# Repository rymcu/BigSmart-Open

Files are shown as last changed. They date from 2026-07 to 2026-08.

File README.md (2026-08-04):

# RYMCU BigSmart AI助手

**中文** | [English](README.en.md)

基于 **ESP32-S3-WROOM-1-N16R8** 的智能语音交互开发板，集成音频系统、显示系统、摄像头、传感器、MicroSD 存储和电池供电等多种外设。

## 主要特性

- **主控**: ESP32-S3-WROOM-1-N16R8 (16 MB Flash + 8 MB PSRAM)
- **音频**: ES8311 DAC + ES7210 四通道 ADC + NS4150B 功放
- **显示**: 2.8" ST7789 LCD (320 x 240) + GT911 电容触摸屏
- **摄像头**: GC0308 (640 x 480 @ 16 FPS)
- **传感器**: QMI8658 六轴加速度计/陀螺仪
- **存储**: MicroSD 卡槽
- **电池**: 2500mAh 3.7V 锂离子电池
- **其他**: WS2812B RGB LED、电池充电管理、按键输入

## 实物展示

| Home | Xiaozhi |
|---|---|
| BigSmart Home | BigSmart Xiaozhi |

| Page 1 | Tetris |
|---|---|
| BigSmart Page 1 | BigSmart Tetris |

## 第三方支持

RYMCU BigSmart 已合并到以下官方开源项目，方便用户基于主线生态进行固件开发和应用验证。

| 小智 AI 官方 | 乐鑫科技 Espressif 官方 |
|---|---|
| [78/xiaozhi-esp32](https://github.com/78/xiaozhi-esp32)<br>[PR #1958](https://github.com/78/xiaozhi-esp32/pull/1958) | [espressif/esp-brookesia](https://github.com/espressif/esp-brookesia)<br>[PR #94](https://github.com/espressif/esp-brookesia/pull/94) |
| RYMCU BigSmart in xiaozhi-esp32 | RYMCU BigSmart in esp-brookesia |

## 开源硬件 PCB 工程

`BigSmart` 硬件由主板和麦克风按键副板组成。硬件文件夹下提供了完整开源工程文件，只需将对应工程导入立创 `EDA` 专业版即可使用。

| 主板 | 麦克风按键副板 |
|---|---|
| BigSmart 主板 PCB | BigSmart 麦克风按键副板 PCB |

## 开源外壳工程

外壳开源，直接3D打印即可。

| 外壳上盖 | 外壳底壳 |
|---|---|
| BigSmart 外壳上盖 | BigSmart 外壳底壳 |

`enclosure/` 同时提供主板与麦克风按键副板的 STEP 结构模型：

- `3D_BigSmart_2026-01-15.step`：主板结构模型，也是网站 3D 主板模型的生成源。
- `3D_bs-mic_2026-02-01.step`：麦克风按键副板结构模型。

修改主板 STEP 后，可在 `site/` 目录运行 `pnpm model:build`，重新生成 `site/public/models/bigsmart-mainboard.glb` 及其元数据。

## 目录结构

```text
BigSmart-Open/
├── hardware/
│   ├── mainboard/          # 主板 EDA 工程及原理图
│   └── mics-keys/          # 麦克风按键板 EDA 工程及原理图
├── enclosure/              # 外壳 3D 设计文件 (Fusion 360)
├── docs/
│   ├── zh/                 # 中文文档
│   └── en/                 # English documentation
├── firmware/               # 预编译合并固件
├── images/                 # 文档引用图片
├── tools/
│   └── video-converter/    # BigSmart 视频转换器
└── README.md
```

## 文档

| 中文 | English |
|---|---|
| [快速使用指南](docs/zh/quick-start.md) | [Quick Start Guide](docs/en/quick-start.md) |
| [产品介绍书](docs/zh/product-brief.md) | [Product Brief](docs/en/product-brief.md) |
| [用户详细使用手册](docs/zh/user-manual.md) | [User Manual](docs/en/user-manual.md) |
| [硬件配置说明](docs/zh/hardware.md) | [Hardware Configuration](docs/en/hardware.md) |
| [视频转换器使用说明](docs/zh/video-converter.md) | [Video Converter User Guide](docs/en/video-converter.md) |

## 固件

- [RYMCU 官方固件](firmware/rymcu-V2.3.28-merged.bin)
- [小智 AI 官方固件](firmware/xiaozhi-esp32-merged.bin)
- [乐鑫科技官方固件](firmware/espressif-brookesia-merged.bin)
- [固件烧录说明](firmware/README.md)

当前推荐使用 `rymcu-V2.3.28-merged.bin`。仓库仍保留 `rymcu-V2.3.19-merged.bin` 作为旧版回退固件。

## 功能展示

点击屏幕的`Music app`和`Video app`即可播放`SD`卡`mp3`音乐和视频。

| 音乐播放 | 视频播放 |
|---|---|
| 音乐播放界面 | 视频播放界面 |

## 许可证

- **个人 DIY / 非商业用途**：遵循 [Apache-2.0](LICENSE) 开源许可证。
- **商业用途**：需取得 RYMCU 商用授权，请联系 [RYMCU 官方](mailto:hugh@rymcu.com) 获取授权详情。

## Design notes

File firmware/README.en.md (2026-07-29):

# RYMCU BigSmart Firmware Flashing Guide

[中文](README.md) | **English**

This directory contains prebuilt merged firmware images that can be flashed directly to the RYMCU BigSmart AI assistant. The images are organized by source: RYMCU official, Xiaozhi AI official, and Espressif official.

## Firmware Images

| File | Source | Description |
|---|---|---|
| `rymcu-V2.3.28-merged.bin` | RYMCU official | Recommended merged firmware image packaged by RYMCU for BigSmart |
| `rymcu-V2.3.19-merged.bin` | RYMCU official | Legacy fallback merged firmware image |
| `xiaozhi-esp32-merged.bin` | Xiaozhi AI official | Merged firmware image for the [78/xiaozhi-esp32](https://github.com/78/xiaozhi-esp32) upstream ecosystem |
| `espressif-brookesia-merged.bin` | Espressif official | Merged firmware image for the [espressif/esp-brookesia](https://github.com/espressif/esp-brookesia) upstream ecosystem |

`rymcu-V2.3.28-merged.bin` is synced from the prebuilt V2.3.28 merged image under `E:\RYMCU\xiaozhi`. It includes Weather, Calendar, Codex Status, Smart Home MQTT/Endpoint overview support, the NES launcher, and NES dedicated boot mode. This prebuilt image does not include the later NES display, audio, and volume-control changes from the 2026-07-28 commit `b1d1c08`.

## Before Flashing

Prepare the following items:

- RYMCU BigSmart AI assistant.
- USB Type-C cable that supports data transfer.
- A Windows computer and any flashing tool that supports ESP32-S3.

Put the device into download mode before flashing:

1. Hold the BigSmart Boot button.
2. Hold the power button to turn on the device.
3. Release all buttons after the device enters download mode.
4. Check the serial port in Device Manager, such as `COM8`.

All flashing methods below require the device to be in download mode first. After flashing, power on the device again to run the new firmware.

## Offline Flashing

Choose any one of the following offline tools. All merged firmware images must be written to Flash offset `0x0`.

### Espressif Flash Download Tool

Flash Download Tool is Espressif's official offline flashing utility. It is suitable for manually selecting the firmware image and writing it through a graphical interface.

Download link: [Flash Download Tool](https://docs.espressif.com/projects/esp-test-tools/en/latest/esp32/production_stage/tools/flash_download_tool.html)

After downloading and extracting the package, run the `.exe` file, then select the chip, serial port, flash address, and firmware image as shown in the tool.

Flash Download Tool start screen

Flash Download Tool flashing configuration

### RYMCU Serial Debug Assistant

RYMCU Serial Debug Assistant provides a graphical serial flashing workflow for quickly selecting and writing a merged firmware image to BigSmart.

Download link: [RYCOM 2.6.3](https://github.com/rymcu/RYCOM/releases/tag/2.6.3)

After installation, open the tool, select the BigSmart serial port, choose the firmware image, and start flashing as shown below.

RYMCU Serial Debug Assistant flashing screen

### RYMCU RODAK Tool

RODAK is a firmware download tool provided by RYMCU. It can also flash BigSmart merged firmware images.

Download link: [RODAK Releases](https://github.com/rymcu/rodak-releases)

After installation, open the tool, select the BigSmart serial port, choose the firmware image, and start flashing as shown below.

RODAK flashing screen

## Online Flashing

### Espressif ESP Launchpad

ESP Launchpad is Espressif's official web flashing tool. It can connect to the serial port and write firmware directly from the browser.

Online flashing link: [ESP Launchpad](https://espressif.github.io/esp-launchpad/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)

Steps:

1. Open the page and click `Connect`.
2. Select the BigSmart serial port in the browser's port list and connect.
3. Click `DIY`.
4. Set the flash address to `0x0`.
5. Select the merged firmware image to flash.
6. Click `Program` to start flashing.

ESP Launchpad flashing screen

## Check After Flashing

After flashing, the device restarts automatically. In a normal startup:

- The screen turns on and enters the Launcher.
- The home screen shows `rymcu-bigsmart` and the firmware version.
- Serial logs print `RYMCU BigSmart - Starting...`.
- If an SD card is inserted, logs show `SD card mounted at /sdcard`.

## Troubleshooting

| Problem | Solution |
|---|---|
| Serial port not found | Use a data-capable USB cable and check drivers/device manager |
| Flashing fails | Re-enter download mode, close any serial terminal using the port, and retry |
| No display after flashing | Confirm the image was written at `0x0`, power-cycle the board, and check power |
| Wi-Fi cannot connect | Use 2.4G Wi-Fi and reconfigure the network in Settings |

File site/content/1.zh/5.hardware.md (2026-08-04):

---
title: 硬件配置说明
description: BigSmart 硬件组件、接口、电源、外设和 GPIO 分配说明。
navigation:
  title: 硬件配置说明
  icon: i-lucide-cpu
links:
  - label: English
    icon: i-lucide-languages
    to: /en/docs/hardware
---
## 概述

RYMCU BigSmart 是一款基于 ESP32-S3 的智能语音交互助手，集成了音频系统、显示系统、摄像头、传感器等多种外设。本文档详细列出了开发板使用的硬件组件及其 GPIO 引脚分配。

## 主控芯片

| 项目 | 规格 |
|---|---|
| 主控 | ESP32-S3-WROOM-1-N16R8 |
| 目标配置 | esp32s3 |
| PSRAM | 支持 |

---

## 1. 音频系统

### 1.1 音频编解码芯片

| 芯片 | 型号 | 功能 | I2C地址 |
|---|---|---|---|
| DAC | ES8311 | 音频输出 | 0x18 |
| ADC | ES7210 | 四通道音频输入 | 0x82（对应硬件7位地址0x41） |

### 1.2 I2S 音频接口

| 功能 | GPIO | 说明 |
|---|---|---|
| MCLK | GPIO38 | 主时钟 |
| WS (LRCK) | GPIO13 | 字选择/左右声道时钟 |
| BCLK | GPIO14 | 位时钟 |
| DIN | GPIO12 | I2S数据输入 (ADC -> ESP32) |
| DOUT | GPIO45 | I2S数据输出 (ESP32 -> DAC) |

### 1.3 麦克风通道映射

ES7210 四通道 ：

MIC1：主麦克风

MIC2：副麦克风

MIC3：AEC参考(连接到音频解码ES8311的输出)

MIC4：悬空

### 1.4 功放

采用NS4150B，使能引脚对应IO0（PCA9557），默认低电平。

### 2 I2C 控制接口

音频编解码器(ES8311/ES7210)、触摸屏(GT911)、IO扩展器(PCA9557)、六轴传感器(QMI8658)共用同一I2C总线.

| 功能 | GPIO | 说明 |
|---|---|---|
| SDA | GPIO1 | I2C数据线 |
| SCL | GPIO2 | I2C时钟线 |

### 3 IO 扩展器 (PCA9557)

| 项目 | 值 |
|---|---|
| 芯片型号 | PCA9557 |
| I2C地址 | 0x19 |
| 功能 | 控制音频编解码器使能引脚 |

IO功能分配：

| IO（PCA9557） | 信号 | 功能 |
| --- | --- | --- |
| IO0 | LCD_CS | 屏幕片选（默认上拉） |
| IO1 | PA_EN | 功放使能（默认下拉） |
| IO2 | DVP_PWDN | 摄像头电源_down（默认上拉） |
| IO3 | NFC_RST  | NFC复位（预留） |
| IO4-IO7 | / | 悬空 |

---

## 4. 显示系统

### 4.1 LCD 显示屏

| 项目 | 规格 |
|---|---|
| 驱动IC | ST7789 |
| 分辨率 | 320 x 240 |
| 接口 | SPI |
| 颜色深度 | 16-bit (RGB565) |
| SPI时钟 | 80 MHz |

### 4.2 SPI 显示接口

| 功能 | GPIO | 说明 |
|---|---|---|
| MOSI | GPIO40 | SPI主输出从输入 |
| SCLK | GPIO41 | SPI时钟 |
| DC | GPIO39 | 数据/命令选择 |
| RESET | / | 上电复位 |
| CS | / | IO0（PCA9557） |

### 4.3 背光控制

| 功能 | GPIO | 说明 |
|---|---|---|
| 背光控制 | GPIO42 | PWM调光 (输出反相) |

### 4.4 触摸屏

| 项目 | 规格 |
|---|---|
| 驱动IC | GT911 |
| 接口 | I2C |
| I2C地址 | 0x5D (默认) / 0x14 (备用) |
| I2C总线 | 与音频共用同一I2C总线 |
| 复位 | 上电复位 |

---

## 5. 摄像头系统

### 5.1 摄像头模块

| 项目 | 规格 |
|---|---|
| 传感器 | GC0308 |
| 接口 | DVP (Digital Video Port) |
| 输出格式 | YUV422 |
| 分辨率 | 640 x 480 |
| 帧率 | 16 FPS |
| XCLK频率 | 16 MHz |

### 5.2 DVP 接口引脚

| 功能 | GPIO | 说明 |
|---|---|---|
| XCLK | GPIO5 | 外部时钟输出 |
| PCLK | GPIO7 | 像素时钟输入 |
| VSYNC | GPIO44 | 垂直同步 |
| HREF | GPIO46 | 水平参考 |
| D0 | GPIO16 | 数据位0 |
| D1 | GPIO18 | 数据位1 |
| D2 | GPIO8 | 数据位2 |
| D3 | GPIO17 | 数据位3 |
| D4 | GPIO15 | 数据位4 |
| D5 | GPIO6 | 数据位5 |
| D6 | GPIO4 | 数据位6 |
| D7 | GPIO9 | 数据位7 |
| SIOD (SDA) | GPIO1 | I2C数据 (共用) |
| SIOC (SCL) | GPIO2 | I2C时钟 (共用) |
| PWDN | / | IO2（PCA9557） |
| RESET | / | 上电复位 |

---

## 6. SD卡接口

### SD 引脚

| 功能 | GPIO | 说明 |
|---|---|---|
| CLK | GPIO47 | 时钟线 |
| CMD | GPIO48 | 命令线 |
| DAT0 | GPIO21 | 数据线0 |
| DAT1 | / | 悬空 |
| DAT2 | / | 悬空 |
| CD/DAT3 | / | 上拉 |

---

## 7. 传感器系统

### 7.1 六轴传感器 (QMI8658)

| 项目 | 规格 |
|---|---|
| 芯片型号 | QMI8658 |
| 功能 | 3轴加速度计 + 3轴陀螺仪 |
| I2C地址 | 0x6A |
| I2C总线 | 与音频共用同一I2C总线 |
| 采样间隔 | 100ms (可配置) |
| 功能 | 姿态检测、晃动检测 |

---

## 8. 按键与LED

### 8.1 按键配置

| 功能 | GPIO | 说明 |
|---|---|---|
| 电源按键 | / | 长按3s开关机  |
| Boot按键 | GPIO0 | 开机/功能按键 |
| 自定义按键 | GPIO10 | 自定义 |
| RGB LED | GPIO43 (UART0_TX复用) | 1颗WS2812B |

---

## 9. 电池监测

| 功能 | GPIO | 说明 |
|---|---|---|
| 充电状态检测 | GPIO3 | 低电平表示正在充电 |
| 电池电压检测 | GPIO11 | 2个10K电阻分压 |

---

## 10. 引脚汇总表

### 10.1 按GPIO编号排序

| GPIO | 功能 | 方向 | 说明 |
|---|---|---|---|
| GPIO0 | Boot按键 | 输入 | 低电平有效 |
| GPIO1 | I2C SDA | 双向 | 音频/触摸/传感器共用 |
| GPIO2 | I2C SCL | 输出 | 音频/触摸/传感器共用 |
| GPIO3 | 充电状态 | 输入 | 低电平表示正在充电 |
| GPIO4 | Camera D6 | 输入 | DVP数据 |
| GPIO5 | Camera XCLK | 输出 | 摄像头时钟 |
| GPIO6 | Camera D5 | 输入 | DVP数据 |
| GPIO7 | Camera PCLK | 输入 | 像素时钟 |
| GPIO8 | Camera D2 | 输入 | DVP数据 |
| GPIO9 | Camera D7 | 输入 | DVP数据 |
| GPIO10 | 按键 | 输入 | 自定义 |
| GPIO11 | 电池电压 | 输入 | 2个10K电阻分压 |
| GPIO12 | I2S DIN | 输入 | ADC数据输入 |
| GPIO13 | I2S WS | 双向 | 字选择 |
| GPIO14 | I2S BCLK | 输出 | 位时钟 |
| GPIO15 | Camera D4 | 输入 | DVP数据 |
| GPIO16 | Camera D0 | 输入 | DVP数据 |
| GPIO17 | Camera D3 | 输入 | DVP数据 |
| GPIO18 | Camera D1 | 输入 | DVP数据 |
| GPIO21 | SD DAT0 | 双向 | SD卡数据 |
| GPIO38 | I2S MCLK | 输出 | 主时钟 |
| GPIO39 | LCD DC | 输出 | 数据/命令选择 |
| GPIO40 | SPI MOSI | 输出 | SPI数据 |
| GPIO41 | SPI SCLK | 输出 | SPI时钟 |
| GPIO42 | 背光控制 | 输出 | PWM (反相) |
| GPIO43 | RGB LED | 输出 | WS2812B数据 |
| GPIO44 | Camera VSYNC | 输入 | 垂直同步 |
| GPIO45 | I2S DOUT | 输出 | DAC数据输出 |
| GPIO46 | Camera HREF | 输入 | 水平参考 |
| GPIO47 | SD CLK | 输出 | SD卡时钟 |
| GPIO48 | SD CMD | 双向 | SD卡命令 |

### 10.2 按功能模块分类

| 模块 | GPIO列表 |
|---|---|
| I2C总线 | GPIO1 (SDA), GPIO2 (SCL) |
| I2S音频 | GPIO38 (MCLK), GPIO13 (WS), GPIO14 (BCLK), GPIO12 (DIN), GPIO45 (DOUT) |
| SPI显示 | GPIO40 (MOSI), GPIO41 (SCLK), GPIO39 (DC) |
| DVP摄像头 | GPIO5, GPIO7, GPIO44, GPIO46, GPIO16, GPIO18, GPIO8, GPIO17, GPIO15, GPIO6, GPIO4, GPIO9 |
| SD卡 | GPIO47 (CLK), GPIO48 (CMD), GPIO21 (DAT0) |
| 背光 | GPIO42 |
| RGB LED | GPIO43 |
| 按键 | GPIO0 (Boot), GPIO10 (自定义) |
| 检测 | GPIO3 (充电状态), GPIO11 (电池电压) |

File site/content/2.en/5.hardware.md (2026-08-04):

---
title: Hardware Configuration
description: Hardware components, interfaces, power, peripherals, and GPIO assignments.
navigation:
  title: Hardware Configuration
  icon: i-lucide-cpu
links:
  - label: 中文
    icon: i-lucide-languages
    to: /docs/hardware
---
## Overview

RYMCU BigSmart is an ESP32-S3 smart voice interaction development board with integrated audio, display, camera, sensor, storage, power, and button peripherals. This document summarizes the main hardware components and GPIO assignments.

## Main Controller

| Item | Specification |
|---|---|
| MCU | ESP32-S3-WROOM-1-N16R8 |
| Target | `esp32s3` |
| PSRAM | Supported |

## 1. Audio System

### 1.1 Audio Codec Chips

| Chip | Model | Function | I2C address |
|---|---|---|---|
| DAC | ES8311 | Audio output | `0x18` |
| ADC | ES7210 | Four-channel audio input | `0x82` eight-bit address, `0x41` seven-bit hardware address |

### 1.2 I2S Audio Interface

| Function | GPIO | Description |
|---|---|---|
| MCLK | GPIO38 | Master clock |
| WS / LRCK | GPIO13 | Word select / left-right clock |
| BCLK | GPIO14 | Bit clock |
| DIN | GPIO12 | I2S data input, ADC to ESP32 |
| DOUT | GPIO45 | I2S data output, ESP32 to DAC |

### 1.3 Microphone Channel Mapping

| ES7210 channel | Function |
|---|---|
| MIC1 | Main microphone |
| MIC2 | Secondary microphone |
| MIC3 | AEC reference, connected to ES8311 output |
| MIC4 | Reserved / floating |

### 1.4 Power Amplifier

The board uses an NS4150B power amplifier. Its enable signal is controlled by IO1 of the PCA9557 and defaults low.

## 2. I2C Control Interface

The ES8311, ES7210, GT911 touch controller, PCA9557 IO expander, and QMI8658 IMU share the same I2C bus.

| Function | GPIO | Description |
|---|---|---|
| SDA | GPIO1 | I2C data |
| SCL | GPIO2 | I2C clock |

## 3. IO Expander

| Item | Value |
|---|---|
| Model | PCA9557 |
| I2C address | `0x19` |
| Function | Controls peripheral enable and selection signals |

| PCA9557 IO | Signal | Function |
|---|---|---|
| IO0 | LCD_CS | LCD chip select, default pull-up |
| IO1 | PA_EN | Amplifier enable, default pull-down |
| IO2 | DVP_PWDN | Camera power down, default pull-up |
| IO3 | NFC_RST | NFC reset, reserved |
| IO4-IO7 | / | Floating |

## 4. Display System

### 4.1 LCD

| Item | Specification |
|---|---|
| Driver IC | ST7789 |
| Resolution | 320 x 240 |
| Interface | SPI |
| Color depth | 16-bit RGB565 |
| SPI clock | 80 MHz |

### 4.2 SPI Display Interface

| Function | GPIO | Description |
|---|---|---|
| MOSI | GPIO40 | SPI data |
| SCLK | GPIO41 | SPI clock |
| DC | GPIO39 | Data/command select |
| RESET | / | Power-on reset |
| CS | / | IO0 of PCA9557 |

### 4.3 Backlight

| Function | GPIO | Description |
|---|---|---|
| Backlight control | GPIO42 | PWM dimming, inverted output |

### 4.4 Touch Panel

| Item | Specification |
|---|---|
| Driver IC | GT911 |
| Interface | I2C |
| I2C address | `0x5D` by default, `0x14` alternative |
| I2C bus | Shared with audio and sensors |
| Reset | Power-on reset |

## 5. Camera System

### 5.1 Camera Module

| Item | Specification |
|---|---|
| Sensor | GC0308 |
| Interface | DVP |
| Output format | YUV422 |
| Resolution | 640 x 480 |
| Frame rate | 16 FPS |
| XCLK frequency | 16 MHz |

### 5.2 DVP Pins

| Function | GPIO | Description |
|---|---|---|
| XCLK | GPIO5 | External clock output |
| PCLK | GPIO7 | Pixel clock input |
| VSYNC | GPIO44 | Vertical sync |
| HREF | GPIO46 | Horizontal reference |
| D0 | GPIO16 | Data bit 0 |
| D1 | GPIO18 | Data bit 1 |
| D2 | GPIO8 | Data bit 2 |
| D3 | GPIO17 | Data bit 3 |
| D4 | GPIO15 | Data bit 4 |
| D5 | GPIO6 | Data bit 5 |
| D6 | GPIO4 | Data bit 6 |
| D7 | GPIO9 | Data bit 7 |
| SIOD / SDA | GPIO1 | Shared I2C data |
| SIOC / SCL | GPIO2 | Shared I2C clock |
| PWDN | / | IO2 of PCA9557 |
| RESET | / | Power-on reset |

## 6. SD Card Interface

| Function | GPIO | Description |
|---|---|---|
| CLK | GPIO47 | Clock |
| CMD | GPIO48 | Command |
| DAT0 | GPIO21 | Data line 0 |
| DAT1 | / | Floating |
| DAT2 | / | Floating |
| CD/DAT3 | / | Pull-up |

## 7. Sensor System

| Item | Specification |
|---|---|
| Model | QMI8658 |
| Function | 3-axis accelerometer + 3-axis gyroscope |
| I2C address | `0x6A` |
| I2C bus | Shared with audio and touch |
| Sampling interval | 100 ms, configurable |
| Typical use | Attitude detection, shake detection |

## 8. Buttons and LED

| Function | GPIO | Description |
|---|---|---|
| Power button | / | Hold for about 3 seconds to power on/off |
| Boot button | GPIO0 | Boot/function button |
| Custom button | GPIO10 | Custom input |
| RGB LED | GPIO43 | One WS2812B LED, reused with UART0_TX |

## 9. Battery Monitoring

| Function | GPIO | Description |
|---|---|---|
| Charging-state detection | GPIO3 | Low level means charging |
| Battery-voltage detection | GPIO11 | Divided by two 10K resistors |

## 10. GPIO Summary

### 10.1 Sorted by GPIO Number

| GPIO | Function | Direction | Description |
|---|---|---|---|
| GPIO0 | Boot button | Input | Active low |
| GPIO1 | I2C SDA | Bidirectional | Shared by audio, touch, and sensors |
| GPIO2 | I2C SCL | Output | Shared by audio, touch, and sensors |
| GPIO3 | Charging state | Input | Low level means charging |
| GPIO4 | Camera D6 | Input | DVP data |
| GPIO5 | Camera XCLK | Output | Camera clock |
| GPIO6 | Camera D5 | Input | DVP data |
| GPIO7 | Camera PCLK | Input | Pixel clock |
| GPIO8 | Camera D2 | Input | DVP data |
| GPIO9 | Camera D7 | Input | DVP data |
| GPIO10 | Button | Input | Custom |
| GPIO11 | Battery voltage | Input | Divided by two 10K resistors |
| GPIO12 | I2S DIN | Input | ADC data input |
| GPIO13 | I2S WS | Bidirectional | Word select |
| GPIO14 | I2S BCLK | Output | Bit clock |
| GPIO15 | Camera D4 | Input | DVP data |
| GPIO16 | Camera D0 | Input | DVP data |
| GPIO17 | Camera D3 | Input | DVP data |
| GPIO18 | Camera D1 | Input | DVP data |
| GPIO21 | SD DAT0 | Bidirectional | SD card data |
| GPIO38 | I2S MCLK | Output | Master clock |
| GPIO39 | LCD DC | Output | Data/command select |
| GPIO40 | SPI MOSI | Output | SPI data |
| GPIO41 | SPI SCLK | Output | SPI clock |
| GPIO42 | Backlight | Output | PWM, inverted |
| GPIO43 | RGB LED | Output | WS2812B data |
| GPIO44 | Camera VSYNC | Input | Vertical sync |
| GPIO45 | I2S DOUT | Output | DAC data output |
| GPIO46 | Camera HREF | Input | Horizontal reference |
| GPIO47 | SD CLK | Output | SD card clock |
| GPIO48 | SD CMD | Bidirectional | SD card command |

### 10.2 Grouped by Function

| Module | GPIO list |
|---|---|
| I2C bus | GPIO1 (SDA), GPIO2 (SCL) |
| I2S audio | GPIO38 (MCLK), GPIO13 (WS), GPIO14 (BCLK), GPIO12 (DIN), GPIO45 (DOUT) |
| SPI display | GPIO40 (MOSI), GPIO41 (SCLK), GPIO39 (DC) |
| DVP camera | GPIO5, GPIO7, GPIO44, GPIO46, GPIO16, GPIO18, GPIO8, GPIO17, GPIO15, GPIO6, GPIO4, GPIO9 |
| SD card | GPIO47 (CLK), GPIO48 (CMD), GPIO21 (DAT0) |
| Backlight | GPIO42 |
| RGB LED | GPIO43 |
| Buttons | GPIO0 (Boot), GPIO10 (custom) |
| Detection | GPIO3 (charging state), GPIO11 (battery voltage) |

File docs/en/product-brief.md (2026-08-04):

# RYMCU BigSmart Product Brief

[中文](../zh/product-brief.md)

## Product Positioning

RYMCU BigSmart is a connected voice and embedded multimedia development platform based on ESP32-S3-WROOM-1-N16R8. It integrates dual-microphone input, speaker output, a 2.8-inch touch display, camera, six-axis IMU, MicroSD storage, and battery power; the repository includes electrical and enclosure project files.

It is intended for Xiaozhi AI terminals, smart home controllers, portable media players, and handheld game prototypes. For pin assignments and hardware details, see [Hardware Configuration](hardware.md). For setup and operation, see the [User Manual](user-manual.md).

## Highlights

| Highlight | Description |
|---|---|
| AI voice interaction | Supports Xiaozhi-style voice assistant firmware, button-triggered conversation, audio capture, speaker playback, and connected services |
| Dual-microphone audio path | ES7210 four-channel ADC with two microphone inputs, one AEC reference, and one reserved channel; ES8311 DAC + NS4150B amplifier |
| Touch display | 2.8-inch ST7789 LCD, 320 x 240 resolution, with GT911 capacitive touch |
| Vision capability | GC0308 DVP camera, 640 x 480 YUV422 capture |
| Portable multimedia | MicroSD card for MP3, video, image, and game resources |
| Motion sensing | QMI8658 six-axis IMU for attitude, shake detection, and interaction triggers |
| Smart home extension | Firmware-side MQTT tools can connect to smart home topics for lights, humidifiers, and other devices |
| Open hardware completeness | Includes mainboard and microphone/button board schematics, EDA files, and Fusion 360 enclosure files |

## Target Users

| User type | Typical use |
|---|---|
| AIoT developers | Validate voice assistants, MCP tools, camera, and local multimedia features |
| Embedded education and makers | Teach ESP32-S3, audio paths, display/touch, SD cards, sensors, and Bluetooth gamepads |
| Smart home users | Use BigSmart as a desktop voice controller connected to Home Assistant, EMQX, or custom services through MQTT |
| Prototype teams | Evaluate portable AI devices, screen-based voice terminals, interactive toys, or handheld controllers |

## Hardware Overview

| Module | Specification |
|---|---|
| MCU | ESP32-S3-WROOM-1-N16R8, 16 MB Flash + 8 MB PSRAM |
| Audio input | ES7210 four-channel ADC, MIC1 main mic, MIC2 secondary mic, MIC3 AEC reference, MIC4 reserved |
| Audio output | ES8311 DAC + NS4150B amplifier |
| Display/touch | ST7789 2.8-inch LCD, 320 x 240; GT911 capacitive touch |
| Camera | GC0308, DVP interface, 640 x 480 @ 16 FPS |
| Storage | MicroSD card slot, firmware uses SDMMC 1-bit mode |
| Sensor | QMI8658 six-axis accelerometer/gyroscope |
| Lighting | One WS2812B RGB LED |
| Buttons | Power button, Boot/function button, GPIO10 PTT/custom button |
| Power | Battery charging management, charging-state detection, battery-voltage detection |

## Software Capabilities

| Capability | Description |
|---|---|
| Wi-Fi provisioning | Enters provisioning on first boot or when no valid network exists; the Xiaozhi project includes BluFi documentation |
| Voice conversation | Boot button toggles conversation state; GPIO10 can be used for push-to-talk |
| Device-side AEC | When `CONFIG_USE_DEVICE_AEC` is enabled, double-clicking Boot toggles AEC while idle |
| Local music | Plays MP3 files from `/sdcard`, with play, stop, list, previous, next, and status tools |
| Internet radio | Plays network audio streams by station name |
| Weather and Calendar | V2.3.28 firmware provides Weather and Calendar app entries |
| Codex Status | Shows Codex runtime status on the device and lets users configure the bridge address in the app |
| Game entry | Opens firmware-provided game features from the Launcher, including the NES launcher and NES dedicated boot mode |
| RGB light control | Supports direct RGB color setting and MQTT light-control topics |
| Smart Home MQTT/Endpoint | Supports Smart Home MQTT broker configuration and MCP Endpoint routing to the same smart home tools |
| IMU attitude | Reads QMI8658 attitude angles, acceleration, gyroscope data, and shake events |
| Camera | Lazy initialization on first camera request to reduce startup memory pressure |

## Typical Applications

### AI Voice Assistant

BigSmart can act as a desktop Xiaozhi terminal. The dual microphones and AEC reference channel support voice interaction, while the display shows state, expressions, menus, or results, and the speaker plays TTS responses.

### Smart Home Controller

Through MQTT tools, voice or MCP commands can publish messages to lights, humidifiers, air conditioners, and other home automation topics. The onboard RGB LED can also serve as local feedback or as an MQTT light example.

### Portable Media Player

The MicroSD card can store MP3 files. Firmware tools support local playback, stop, file listing, previous/next track, and playback status, making BigSmart suitable for a desktop music terminal or classroom experiment.

### ESP32-S3 Handheld Gaming Experiment

With LCD, speaker, SD card, and Bluetooth HID gamepad support, BigSmart can be used for ESP32-S3 handheld game experiments and custom game demos.

### Multi-sensor Interactive Device

The QMI8658 provides attitude and shake events, the camera captures images, and the touch screen and RGB LED provide feedback, making the board useful for interactive demos and education projects.

## Repository Resources

| Path | Content |
|---|---|
| `hardware/mainboard/` | Mainboard EDA project and schematics |
| `hardware/mics-keys/` | Microphone/button board EDA project and schematics |
| `enclosure/` | Fusion 360 enclosure files |
| `docs/en/hardware.md` | Hardware components, pin assignments, and GPIO summary |
| `docs/en/user-manual.md` | Unboxing, flashing, network setup, operation, and troubleshooting |

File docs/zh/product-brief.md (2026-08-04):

# RYMCU BigSmart 产品介绍书

[English](../en/product-brief.md)

## 产品定位

RYMCU BigSmart 是基于 ESP32-S3-WROOM-1-N16R8 的联网语音与嵌入式多媒体开发平台。设备集成双麦拾音、扬声器输出、2.8 英寸触摸屏、摄像头、六轴 IMU、MicroSD 与电池供电，仓库提供电路和外壳工程文件。适用于小智 AI 终端、智能家居中控、便携式媒体播放器和掌机原型等开发场景。

本介绍书面向选型、展示、二次开发和课程教学场景。具体引脚和硬件细节请参阅 [硬件配置说明](hardware.md)，上手操作请参阅 [用户详细使用手册](user-manual.md)。

## 核心亮点

| 亮点 | 说明 |
|---|---|
| AI 语音交互 | 可运行小智 AI 类语音助手固件，支持按键对话、音频采集、扬声器播放和联网服务 |
| 双麦与音频链路 | ES7210 四通道 ADC（双麦输入、AEC 参考、一路悬空）+ ES8311 DAC + NS4150B 功放 |
| 彩屏触控 | 2.8 英寸 ST7789 LCD，320 x 240 分辨率，配套 GT911 电容触摸 |
| 视觉能力 | GC0308 DVP 摄像头，支持 640 x 480 YUV422 图像采集 |
| 便携多媒体 | MicroSD 卡槽可存放 MP3、视频、图片和游戏资源，支持本地音乐播放与多媒体资源读取 |
| 体感与状态感知 | QMI8658 六轴 IMU 可用于姿态检测、晃动检测与交互触发 |
| 智能家居扩展 | 固件侧可通过 MQTT 工具连接智能家居主题，控制 RGB 灯、加湿器等设备 |
| 开源硬件完整度 | 仓库包含主板、麦克风按键板原理图/EDA 工程，以及 Fusion 360 外壳文件 |

## 目标用户

| 用户类型 | 典型用途 |
|---|---|
| AIoT 开发者 | 快速验证语音助手、MCP 工具、摄像头和本地多媒体功能 |
| 嵌入式课程/创客教育 | 讲解 ESP32-S3、音频链路、显示触摸、SD 卡、传感器和蓝牙手柄 |
| 智能家居玩家 | 作为桌面语音中控，通过 MQTT 与 Home Assistant、EMQX 或自建服务联动 |
| 产品原型团队 | 评估便携式 AI 设备、带屏语音终端、互动玩具、掌机式控制器的硬件形态 |

## 硬件组成

| 模块 | 规格 |
|---|---|
| 主控 | ESP32-S3-WROOM-1-N16R8，16 MB Flash + 8 MB PSRAM |
| 音频输入 | ES7210 四通道 ADC，MIC1 主麦克风、MIC2 副麦克风、MIC3 AEC 参考、MIC4 预留 |
| 音频输出 | ES8311 DAC + NS4150B 功放 |
| 显示触摸 | ST7789 2.8 英寸 LCD，320 x 240；GT911 电容触摸 |
| 摄像头 | GC0308，DVP 接口，640 x 480 @ 16 FPS |
| 存储 | MicroSD 卡槽，固件使用 SDMMC 1 线模式 |
| 传感器 | QMI8658 六轴加速度计/陀螺仪 |
| 灯光 | 1 颗 WS2812B RGB LED |
| 按键 | 电源键、Boot/功能键、GPIO10 PTT/自定义键 |
| 供电 | 电池充电管理、充电状态检测、电池电压检测 |

## 软件能力

主要能力包括：

| 能力 | 说明 |
|---|---|
| Wi-Fi 配网 | 首次启动或无有效网络时进入配网；小智工程包含 BluFi 配网说明 |
| 语音对话 | Boot 键单击切换对话状态，GPIO10 支持按住说话 |
| 设备侧 AEC | 固件启用 `CONFIG_USE_DEVICE_AEC` 时，Boot 键双击可切换 AEC |
| 本地音乐 | 支持从 `/sdcard` 播放 MP3，包含播放、停止、列表、上一首、下一首、状态查询等工具 |
| 网络电台 | 支持按电台名称播放网络音频流 |
| 天气与日历 | V2.3.28 固件提供天气和日历应用入口 |
| Codex 状态 | 可在设备端查看 Codex 运行状态，并在应用中配置桥接地址 |
| 游戏入口 | 支持通过 Launcher 进入固件提供的游戏相关功能，包含 NES 启动器和 NES 专用启动模式 |
| RGB 灯控 | 支持直接设置 RGB 颜色，也可通过 MQTT 灯控主题联动 |
| Smart Home MQTT/Endpoint | 支持配置 Smart Home MQTT broker，也可通过 MCP Endpoint 桥接到同一套智能家居工具 |
| IMU 姿态 | 可读取 QMI8658 姿态角、加速度与陀螺仪数据，并支持晃动检测 |
| 摄像头 | 首次请求摄像头时懒加载初始化，降低启动阶段内存压力 |

## 典型应用方案

### AI 语音助手

BigSmart 可作为桌面小智终端。双麦输入和 AEC 参考通道用于语音交互，屏幕用于显示状态、表情、菜单或结果，扬声器用于 TTS 播报。

### 智能家居中控

通过 MQTT 工具连接到家庭 broker，语音或 MCP 指令可发布到灯光、加湿器、空调等主题。板载 RGB LED 可作为本地灯控反馈，也可作为 MQTT 灯光示例设备。

### 便携媒体播放器

MicroSD 卡用于存放 MP3 文件。固件提供本地播放、停止、歌曲列表、上一首、下一首和播放状态查询能力，适合做桌面音乐终端或课程实验。

### ESP32-S3 掌机实验

结合 LCD、扬声器、SD 卡和蓝牙 HID 手柄，BigSmart 可用于 ESP32-S3 掌机类实验和自定义游戏演示。

### 多传感互动装置

QMI8658 可读取姿态和晃动事件，摄像头可采集图像，触摸屏和 RGB LED 提供反馈，适合制作互动展示、体感控制或教育实验。

## 资料清单

| 目录/文件 | 内容 |
|---|---|
| `hardware/mainboard/` | 主板 EDA 工程与原理图 |
| `hardware/mics-keys/` | 麦克风按键板 EDA 工程与原理图 |
| `enclosure/` | 外壳 Fusion 360 设计文件 |
| `docs/zh/hardware.md` | 硬件组件、引脚分配和 GPIO 汇总 |
| `docs/zh/user-manual.md` | 开箱、烧录、配网、使用和故障排查 |

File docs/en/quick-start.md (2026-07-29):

# RYMCU BigSmart Quick Start Guide

[中文](../zh/quick-start.md)

This guide is written for the **RYMCU BigSmart AI assistant**. It helps users complete first boot, network setup, voice interaction, `SD` card resource preparation, music playback, video playback, and `USB` disk mode.

For complete build, flashing, and hardware details, see the [User Manual](user-manual.md) and [Hardware Configuration](hardware.md).

<p align="center">RYMCU BigSmart layout</p>

## 1. Firmware and Flashing

`BigSmart` ships with the `RYMCU` official firmware preinstalled and can be used directly after power-on. To upgrade or switch firmware, see the [firmware flashing guide](../../firmware/README.en.md).

The firmware images in this repository are merged images. When using a flashing tool, write the image to `Flash` offset `0x0`.

The recommended image is `rymcu-V2.3.28-merged.bin`; `rymcu-V2.3.19-merged.bin` remains available as a legacy fallback. The V2.3.28 prebuilt image includes Weather, Calendar, Codex Status, Smart Home MQTT/Endpoint, the NES launcher, and NES dedicated boot mode. It does not include the later NES display, audio, and volume-control changes from the 2026-07-28 commit `b1d1c08`.

## 2. Power On and Home Screen

### 2.1 Power On

1. Hold the power button for about `3` seconds to power on. When powered on, hold it again to power off.
2. If the battery is low, connect the board to a computer or `5V` power supply with a `USB Type-C` data cable.
3. After the screen turns on, the `Home` screen appears and shows `rymcu-bigsmart` and the current firmware version.
4. To view logs, connect to the corresponding `COM` port with a serial terminal.

<p align="center">BigSmart Home screen</p>

### 2.2 Home Screen and Apps

Swipe left or right on the `Home` screen to switch app pages. Common apps include:

| App | Purpose |
|-----|---|
| Xiaozhi | Start the Xiaozhi voice assistant |
| Settings | Configure Wi-Fi, server, display, and other settings |
| Music | Play MP3 files from the SD card |
| Radio | Play internet radio |
| Weather | View weather information |
| Calendar | View the calendar |
| Video | Play video resources from `/sdcard/videos` |
| Image | View image resources |
| Camera | Use the GC0308 camera |
| Gyro | View QMI8658 attitude and sensor information |
| Codex | View Codex status and bridge settings entry |
| NES | Select an NES ROM from the SD card and reboot into NES dedicated boot mode |
| Games | Enter game-related features |
| USB Disk | Reboot into USB disk mode and share the SD card with a PC |

Use the touch screen to open apps, go back, select files, and adjust settings.

<p align="center">BigSmart app page</p>

## 3. Wi-Fi Setup

`Wi-Fi` must be configured before first use. `BigSmart` supports three provisioning methods: on-screen setup, hotspot web setup, and WeChat mini program BLE setup. Choose any one of them.

Open the `Settings` app and enter the `Wi-Fi` settings page.

<p align="center">Wi-Fi settings entry</p>

**Note: BigSmart supports 2.4 GHz Wi-Fi only.**

### 3.1 On-screen Wi-Fi Setup

Tap `Screen WiFi`, enter the `Wi-Fi` SSID and password, and tap `Connect`.

<p align="center">On-screen Wi-Fi setup</p>

### 3.2 Hotspot Web Setup

Tap `Web Setup` to open hotspot provisioning. Connect your phone to the hotspot shown on the screen, such as `Xiaozhi-11F0`. The phone usually opens the setup page automatically; if not, open the browser page shown by the device and enter the `Wi-Fi` information manually.

<p align="center">Hotspot web setup</p>

### 3.3 WeChat Mini Program BLE Setup

Tap `BLE Setup` to open BLE provisioning. Scan the QR code on the device with WeChat, or search for the mini program `艾塔达克`. Register or sign in before provisioning if prompted.

<p align="center">WeChat mini program BLE entry</p>

Mini program flow:

| Open the mini program | Select BLE setup | Complete Wi-Fi setup |
|---|---|---|
| WeChat mini program step 1 | WeChat mini program step 2 | WeChat mini program step 3 |

## 4. Service Provider and Device Binding

### 4.1 Service Provider Settings

Before using the `xiaozhi` voice assistant, set the server address first. The screen configuration supports three service provider options. Open the `Settings` app and tap `Advanced`, as shown below.

<p align="center">Advanced service settings</p>

Here, `atdak` is the `RYMCU` official server, `tenclass` is the Xiage Xiaozhi AI official server, and `custom` is a custom server where you can enter your own server address.

**The factory default uses the RYMCU official server.**

### 4.2 Device Binding

For first-time use, after entering the `Xiaozhi app`, the device screen shows an activation code or binding code. Enter that code in the corresponding mini program or web console and confirm the binding.

<p align="center">Device binding code</p>

**Choose any one of the following three methods. Make sure it matches the configured service provider. The factory default is the first one.**

#### 4.2.1 RYMCU Official Server Verification-Code Binding

Log in to the WeChat mini program "艾塔达克" and bind the device as shown below.

| Device list entry | Enter binding information |
|---|---|
| Device binding step 1 | Device binding step 2 |

#### 4.2.2 tenclass Xiaozhi AI Official Server Verification-Code Binding

Log in to the official console at https://xiaozhi.me/console/agents, click "Device Management", then click "Add Device". Enter the 6-digit verification code spoken by the device or shown on the screen in the add-device dialog.

<p align="center">Web console add-device dialog</p>

#### 4.2.3 Custom Server Verification-Code Binding

Bind the device according to your custom server.

In addition, the `RYMCU` official server is open source and can be self-deployed if you have the required technical foundation. Server link: https://github.com/ruanrongman/IntelliConnect

## 5. AI Assistant Usage

**After `wifi` and server configuration are complete, tap the `xiaozhi app` on the screen to enter the AI assistant. After initialization finishes and the `idle` page appears, wake it by saying "Ni hao, Xiaozhi", or press the middle `boot` button to wake it.**

| Idle page | Wakeup page |
|---|---|
| AI assistant idle page | AI assistant wakeup page |

## 6. Music and Video Playback

Tap the `Music app` and `Video app` on the screen to play `mp3` music and videos from the `SD` card.

| Music playback | Video playback |
|---|---|
| Music playback screen | Video playback screen |

**Copy `mp3` music and video files to the `music` and `videos` folders on the `SD` card in advance. See the next section for the operation method.**

## 7. USB Disk Mode

`USB` disk mode shares the `SD` card with a computer as a `USB` drive. It is useful for quickly copying music, videos, background images, and other resources.

Enter USB disk mode:

Tap the `USB Disk app` on the screen to enter `USB`-to-drive mode. Connect the device to a computer with a `USB` cable, and the computer will show the `SD` card as a `USB` drive.

<p align="center">SD card folders in USB disk mode</p>

**Copy `MP3` files to the `music` folder.**

**Regular video files need to be converted to a format suitable for playback on the `bigsmart AI` assistant, then placed in the `videos` directory. Use the repository [Video Converter](video-converter.md) for conversion.**

## 8. Internet Radio

Tap the `Radio app` to play internet radio stations.

<p align="center">Internet radio</p>

## 9. Games

Tap the `Games app` to play multiple games.

| Game list | Maze game |
|---|---|
| Game list | Maze game |

## 10. Extended Features

`BigSmart` firmware also registers local features and `MCP` tools:

| Feature | Description |
|---|---|
| Weather and Calendar | V2.3.28 firmware provides Weather and Calendar app entries |
| Codex Status | Shows Codex runtime status and bridge settings on the device |
| RGB LED | Set RGB colors and turn the light off |
| IMU attitude and shake | QMI8658 reads attitude data and supports shake detection |
| Smart Home MQTT/Endpoint | Configures the Smart Home MQTT broker and routes MCP Endpoint calls to the same smart home tools |
| NES dedicated boot mode | Selects an SD-card ROM from the NES launcher and reboots into the dedicated mode |
| Camera | GC0308 is lazily initialized when opening Camera or requesting camera capability for the first time |

## 11. Troubleshooting

| Problem | Suggestion |
|---|---|
| Screen does not turn on | Hold the power button for about 3 seconds; check battery level, USB power, and cable |
| No serial port on PC | Use a data-capable USB cable and check drivers/device manager |
| Wi-Fi not found | Use 2.4 GHz Wi-Fi and retry near the router |
| Cannot enter Wi-Fi setup | Open the Wi-Fi page from `Settings`, or reboot and restart the provisioning flow |
| SD card mount fails | Use FAT32, reinsert the card, or try another card |
| Video app shows no files | Put files under `/sdcard/videos`; at least a `.mjpg` file is required |
| Video has no sound | Make sure a same-name `.mp3` file exists |
| Video speed is wrong | Make sure the same-name `.fps` file contains an integer frame rate |
| MP3 playback fails | Use an absolute `/sdcard/...` path and confirm the `.mp3` extension |
| USB disk mode does not enter | Hold GPIO10 before startup/reset and make sure an SD card is inserted |
| NES games are not listed | Make sure the SD card is mounted and `.nes` ROMs are in the firmware-recognized SD card directory |
| Codex status cannot connect | Make sure the device and PC are on the same LAN and the bridge address is configured in the Codex app |
| Voice recognition has echo | Double-click Boot while idle to toggle device-side AEC |

## 12. Next Reading

- [Product Brief](product-brief.md)
- [User Manual](user-manual.md)
- [Hardware Configuration](hardware.md)
- [Video Converter User Guide](video-converter.md)

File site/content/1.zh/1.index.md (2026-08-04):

---
title: RYMCU BigSmart AI助手
description: ESP32-S3 智能语音交互开发板文档、硬件资料、固件与工具。
navigation:
  title: 概览
  icon: i-lucide-house
links:
  - label: English
    icon: i-lucide-languages
    to: /en/docs
---
基于 **ESP32-S3-WROOM-1-N16R8** 的智能语音交互开发板，集成音频系统、显示系统、摄像头、传感器、MicroSD 存储和电池供电等多种外设。

## 主要特性

- **主控**: ESP32-S3-WROOM-1-N16R8 (16 MB Flash + 8 MB PSRAM)
- **音频**: ES8311 DAC + ES7210 四通道 ADC + NS4150B 功放
- **显示**: 2.8" ST7789 LCD (320 x 240) + GT911 电容触摸屏
- **摄像头**: GC0308 (640 x 480 @ 16 FPS)
- **传感器**: QMI8658 六轴加速度计/陀螺仪
- **存储**: MicroSD 卡槽
- **电池**: 2500mAh 3.7V 锂离子电池
- **其他**: WS2812B RGB LED、电池充电管理、按键输入

## 实物展示

| Home | Xiaozhi |
|---|---|
| BigSmart Home | BigSmart Xiaozhi |

| Page 1 | Tetris |
|---|---|
| BigSmart Page 1 | BigSmart Tetris |

## 第三方支持

RYMCU BigSmart 已合并到以下官方开源项目，方便用户基于主线生态进行固件开发和应用验证。

| 小智 AI 官方 | 乐鑫科技 Espressif 官方 |
|---|---|
| [78/xiaozhi-esp32](https://github.com/78/xiaozhi-esp32)<br>[PR #1958](https://github.com/78/xiaozhi-esp32/pull/1958) | [espressif/esp-brookesia](https://github.com/espressif/esp-brookesia)<br>[PR #94](https://github.com/espressif/esp-brookesia/pull/94) |
| RYMCU BigSmart in xiaozhi-esp32 | RYMCU BigSmart in esp-brookesia |

## 开源硬件 PCB 工程

`BigSmart` 硬件由主板和麦克风按键副板组成。硬件文件夹下提供了完整开源工程文件，只需将对应工程导入立创 `EDA` 专业版即可使用。

| 主板 | 麦克风按键副板 |
|---|---|
| BigSmart 主板 PCB | BigSmart 麦克风按键副板 PCB |

## 开源外壳工程

外壳开源，直接3D打印即可。

| 外壳上盖 | 外壳底壳 |
|---|---|
| BigSmart 外壳上盖 | BigSmart 外壳底壳 |

## 目录结构

```text
BigSmart-Open/
├── hardware/
│   ├── mainboard/          # 主板 EDA 工程及原理图
│   └── mics-keys/          # 麦克风按键板 EDA 工程及原理图
├── enclosure/              # 外壳 3D 设计文件 (Fusion 360)
├── docs/
│   ├── zh/                 # 中文文档
│   └── en/                 # English documentation
├── firmware/               # 预编译合并固件
├── images/                 # 文档引用图片
├── tools/
│   └── video-converter/    # BigSmart 视频转换器
└── README.md
```

## 文档

| 中文 | English |
|---|---|
| [快速使用指南](/docs/quick-start) | [Quick Start Guide](/en/docs/quick-start) |
| [产品介绍书](/docs/product-brief) | [Product Brief](/en/docs/product-brief) |
| [用户详细使用手册](/docs/user-manual) | [User Manual](/en/docs/user-manual) |
| [硬件配置说明](/docs/hardware) | [Hardware Configuration](/en/docs/hardware) |
| [视频转换器使用说明](/docs/video-converter) | [Video Converter User Guide](/en/docs/video-converter) |

## 固件

- [RYMCU 官方固件](https://github.com/rymcu/BigSmart-Open/raw/main/firmware/rymcu-V2.3.28-merged.bin)
- [小智 AI 官方固件](https://github.com/rymcu/BigSmart-Open/raw/main/firmware/xiaozhi-esp32-merged.bin)
- [乐鑫科技官方固件](https://github.com/rymcu/BigSmart-Open/raw/main/firmware/espressif-brookesia-merged.bin)
- [固件烧录说明](/docs/firmware)

当前推荐使用 `rymcu-V2.3.28-merged.bin`。仓库仍保留 `rymcu-V2.3.19-merged.bin` 作为旧版回退固件。

## 功能展示

点击屏幕的`Music app`和`Video app`即可播放`SD`卡`mp3`音乐和视频。

| 音乐播放 | 视频播放 |
|---|---|
| 音乐播放界面 | 视频播放界面 |

## 许可证

- **个人 DIY / 非商业用途**：遵循 [Apache-2.0](https://github.com/rymcu/BigSmart-Open/blob/main/LICENSE) 开源许可证。
- **商业用途**：需取得 RYMCU 商用授权，请联系 [RYMCU 官方](mailto:hugh@rymcu.com) 获取授权详情。

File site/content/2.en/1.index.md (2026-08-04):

---
title: RYMCU BigSmart Development Board
description: Documentation, hardware resources, firmware, and tools for the ESP32-S3 smart voice interaction board.
navigation:
  title: Overview
  icon: i-lucide-house
links:
  - label: 中文
    icon: i-lucide-languages
    to: /docs
---
RYMCU BigSmart is a smart voice interaction development board based on **ESP32-S3-WROOM-1-N16R8**. It integrates audio, display, camera, sensors, MicroSD storage, battery power, and other peripherals.

## Key Features

- **MCU**: ESP32-S3-WROOM-1-N16R8 (16 MB Flash + 8 MB PSRAM)
- **Audio**: ES8311 DAC + ES7210 four-channel ADC + NS4150B power amplifier
- **Display**: 2.8" ST7789 LCD (320 x 240) + GT911 capacitive touch panel
- **Camera**: GC0308 (640 x 480 @ 16 FPS)
- **Sensor**: QMI8658 six-axis accelerometer/gyroscope
- **Storage**: MicroSD card slot
- **Battery**: 2500mAh 3.7V lithium-ion battery
- **Other**: WS2812B RGB LED, battery charging management, button input

## Showcase

| Home | Xiaozhi |
|---|---|
| BigSmart Home | BigSmart Xiaozhi |

| Page 1 | Tetris |
|---|---|
| BigSmart Page 1 | BigSmart Tetris |

## Third-party Support

RYMCU BigSmart has been merged into the following official open source projects, making it easier to build firmware and validate applications on top of their upstream ecosystems.

| Xiaozhi AI Official | Espressif Official |
|---|---|
| [78/xiaozhi-esp32](https://github.com/78/xiaozhi-esp32)<br>[PR #1958](https://github.com/78/xiaozhi-esp32/pull/1958) | [espressif/esp-brookesia](https://github.com/espressif/esp-brookesia)<br>[PR #94](https://github.com/espressif/esp-brookesia/pull/94) |
| RYMCU BigSmart in xiaozhi-esp32 | RYMCU BigSmart in esp-brookesia |

## Open Source Hardware PCB Project

The BigSmart hardware consists of a mainboard and a microphone/button daughter board. Complete open source hardware project files are provided in the hardware folder. Import the corresponding project into LCSC EDA Professional to use it.

| Mainboard | Microphone/Button Board |
|---|---|
| BigSmart mainboard PCB | BigSmart microphone/button board PCB |

## Open Source Enclosure Project

The enclosure is open source and can be used directly for 3D printing.

| Top Cover | Bottom Shell |
|---|---|
| BigSmart top cover | BigSmart bottom shell |

## Repository Layout

```text
BigSmart-Open/
├── hardware/
│   ├── mainboard/          # Mainboard EDA project and schematics
│   └── mics-keys/          # Microphone/button board EDA project and schematics
├── enclosure/              # Fusion 360 enclosure design files
├── docs/
│   ├── zh/                 # Chinese documentation
│   └── en/                 # English documentation
├── firmware/               # Prebuilt merged firmware images
├── images/                 # Images referenced by documentation
├── tools/
│   └── video-converter/    # BigSmart video converter
└── README.md
```

## Documentation

| English | 中文 |
|---|---|
| [Quick Start Guide](/en/docs/quick-start) | [快速使用指南](/docs/quick-start) |
| [Product Brief](/en/docs/product-brief) | [产品介绍书](/docs/product-brief) |
| [User Manual](/en/docs/user-manual) | [用户详细使用手册](/docs/user-manual) |
| [Hardware Configuration](/en/docs/hardware) | [硬件配置说明](/docs/hardware) |
| [Video Converter User Guide](/en/docs/video-converter) | [视频转换器使用说明](/docs/video-converter) |

## Firmware

- [RYMCU official firmware](https://github.com/rymcu/BigSmart-Open/raw/main/firmware/rymcu-V2.3.28-merged.bin)
- [Xiaozhi AI official firmware](https://github.com/rymcu/BigSmart-Open/raw/main/firmware/xiaozhi-esp32-merged.bin)
- [Espressif official firmware](https://github.com/rymcu/BigSmart-Open/raw/main/firmware/espressif-brookesia-merged.bin)
- [Firmware flashing guide](/en/docs/firmware)

The recommended image is now `rymcu-V2.3.28-merged.bin`. `rymcu-V2.3.19-merged.bin` remains available as a legacy fallback image.

## Feature Showcase

Tap the `Music app` and `Video app` on the screen to play `mp3` music and videos from the `SD` card.

| Music Playback | Video Playback |
|---|---|
| Music playback screen | Video playback screen |

## License

- **Personal DIY / non-commercial use**: licensed under [Apache-2.0](https://github.com/rymcu/BigSmart-Open/blob/main/LICENSE).
- **Commercial use**: requires commercial authorization from RYMCU. Contact [RYMCU](mailto:hugh@rymcu.com) for licensing details.

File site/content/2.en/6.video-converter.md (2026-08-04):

---
title: Video Converter User Guide
description: Convert common video files into resources playable by BigSmart firmware.
navigation:
  title: Video Converter User Guide
  icon: i-lucide-video
links:
  - label: 中文
    icon: i-lucide-languages
    to: /docs/video-converter
---
RYMCU BigSmart Video Converter converts common video files into resources that can be played by the BigSmart firmware. After conversion, the tool generates `.mjpg`, `.mp3`, and `.fps` files with the same base name. Copy all three files to the `/videos` directory on the SD card to play them on the device.

## Tool Location

```text
tools/video-converter/RYMCU-Video-Converter.exe
```

FFmpeg is bundled with the tool, so the target computer does not need a separate FFmpeg installation.

## Supported Formats

Common video formats are supported, including:

- `mp4`
- `mov`
- `avi`
- `mkv`
- `flv`
- `webm`
- `m4v`
- `wmv`
- `3gp`

## Conversion Steps

1. Double-click `tools/video-converter/RYMCU-Video-Converter.exe`.
2. Click "Select Video", or drag a video file into the window.
3. Keep the default parameters, or adjust them as needed.
4. Click "Start Conversion".
5. After conversion, check that the output directory contains three files:

```text
video-name.mjpg
video-name.mp3
video-name.fps
```

## Recommended Settings

| Setting | Recommended value | Notes |
|---|---|---|
| Video frame rate | 8-12 fps | Recommended for a balance between smooth playback and decoding load |
| Fast-motion video | 12-15 fps | Smoother playback, but larger files and higher decoding load |
| JPEG quality | 8 | Default recommended value |
| MP3 sample rate | 44100 Hz | Default recommended value |
| Smaller audio files | 16000 Hz | Optional when reducing audio size is more important |

The matching firmware reads the `.fps` file with the same base name to keep audio and video synchronized.

## Copy Files to the SD Card

Copy the three generated files to the `/videos` directory on the SD card:

```text
/sdcard/videos/video-name.mjpg
/sdcard/videos/video-name.mp3
/sdcard/videos/video-name.fps
```

If the SD card does not contain a `videos` directory, create it manually first.

## Notes

- The three output files must keep the same base name. Only the file extensions should differ.
- Use English letters, numbers, hyphens, or underscores in video file names for better path compatibility across systems.
- Higher frame rates and higher image quality produce larger files and increase the decoding load on the device.
- If playback is not smooth, lower the frame rate or JPEG quality first.

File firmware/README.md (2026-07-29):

# RYMCU BigSmart 固件烧录说明

**中文** | [English](README.en.md)

本目录存放 RYMCU BigSmart AI 助手可直接烧录的预编译合并固件。固件按来源分为 RYMCU 官方、小智 AI 官方和乐鑫科技官方三个版本。

## 固件文件

| 文件 | 来源 | 说明 |
|---|---|---|
| `rymcu-V2.3.28-merged.bin` | RYMCU 官方 | RYMCU 针对 BigSmart 整理发布的推荐合并固件 |
| `rymcu-V2.3.19-merged.bin` | RYMCU 官方 | 旧版回退合并固件 |
| `xiaozhi-esp32-merged.bin` | 小智 AI 官方 | 对应 [78/xiaozhi-esp32](https://github.com/78/xiaozhi-esp32) 主线生态的合并固件 |
| `espressif-brookesia-merged.bin` | 乐鑫科技官方 | 对应 [espressif/esp-brookesia](https://github.com/espressif/esp-brookesia) 主线生态的合并固件 |

`rymcu-V2.3.28-merged.bin` 基于 `E:\RYMCU\xiaozhi` 中已生成的 V2.3.28 合并固件同步，包含天气、日历、Codex 状态应用、Smart Home MQTT/Endpoint 概览能力、NES 启动器和 NES 专用启动模式。该预编译文件不包含 2026-07-28 提交 `b1d1c08` 中后续的 NES 显示、音频和音量控制调整。

## 烧录前准备

准备以下物品：

- RYMCU BigSmart AI 助手。
- 可传输数据的 USB Type-C 数据线。
- Windows 电脑和任一支持 ESP32-S3 的烧录工具。

烧录前需要先让设备进入下载模式：

1. 按住 BigSmart 的 Boot 按键不放。
2. 长按电源按键开机。
3. 设备进入下载模式后松开全部按键。
4. 在设备管理器中查看串口号，例如 `COM8`。

后续所有烧录方式都需要先完成以上步骤。烧录完成后，重新开机即可运行新固件。

## 离线烧录方式

以下三种离线烧录工具任选其一即可。所有合并固件都需要写入 Flash 偏移地址 `0x0`。

### 乐鑫 Flash Download Tool

Flash Download Tool 是乐鑫官方离线烧录工具，适合使用图形界面手动选择固件并写入设备。

工具下载链接：[Flash Download Tool](https://docs.espressif.com/projects/esp-test-tools/en/latest/esp32/production_stage/tools/flash_download_tool.html)

下载并解压后，找到 `.exe` 文件双击运行，按界面提示选择芯片、串口、烧录地址和固件文件。

Flash Download Tool 启动界面

Flash Download Tool 烧录配置

### RYMCU 串口调试助手

RYMCU 串口调试助手提供图形化串口烧录入口，适合快速选择合并固件并写入 BigSmart。

工具下载链接：[RYCOM 2.6.3](https://github.com/rymcu/RYCOM/releases/tag/2.6.3)

安装并打开软件后，选择 BigSmart 对应串口，按图示选择固件文件并开始烧录。

RYMCU 串口调试助手烧录界面

### RYMCU RODAK 工具

RODAK 是 RYMCU 提供的固件下载工具，也可用于烧录 BigSmart 合并固件。

工具下载链接：[RODAK Releases](https://github.com/rymcu/rodak-releases)

安装并打开软件后，选择 BigSmart 对应串口，按图示选择固件文件并开始烧录。

RODAK 烧录界面

## 在线烧录方式

### 乐鑫 ESP Launchpad

ESP Launchpad 是乐鑫官方网页烧录工具，可直接在浏览器中连接串口并写入固件。

在线烧录链接：[ESP Launchpad](https://espressif.github.io/esp-launchpad/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)

操作步骤：

1. 打开网页后点击 `Connect`。
2. 在浏览器弹出的串口列表中选择 BigSmart 对应串口并连接。
3. 点击 `DIY`。
4. 将烧录地址设置为 `0x0`。
5. 选择需要烧录的合并固件。
6. 点击 `Program` 开始烧录。

ESP Launchpad 烧录界面

## 烧录后检查

烧录完成后设备会自动重启。正常情况下可以看到：

- 屏幕亮起并进入 Launcher。
- 主界面显示 `rymcu-bigsmart` 和固件版本。
- 串口日志打印 `RYMCU BigSmart - Starting...`。
- 若已插入 SD 卡，日志显示 `SD card mounted at /sdcard`。

## 常见问题

| 问题 | 处理方法 |
|---|---|
| 找不到串口 | 更换可传输数据的 USB 线，检查驱动和设备管理器 |
| 烧录失败 | 重新进入下载模式，关闭占用串口的串口终端后重试 |
| 烧录后无显示 | 确认固件写入地址为 `0x0`，重新上电，检查供电 |
| Wi-Fi 无法连接 | 使用 2.4G Wi-Fi，在 Settings 中重新配网 |

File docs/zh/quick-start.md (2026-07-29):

# RYMCU BigSmart 快速使用指南

[English](../en/quick-start.md)

本指南面向 **RYMCU BigSmart AI 助手**，用于帮助用户快速完成开机、联网、语音交互、`SD` 卡资源准备、音乐播放、视频播放和 `USB` 磁盘模式等基础操作。

更完整的编译、烧录和外设说明请参考 [用户详细使用手册](user-manual.md) 与 [硬件配置说明](hardware.md)。

<p align="center">RYMCU BigSmart 布局图</p>

## 1. 固件与烧录

`BigSmart` 出厂已预装 `RYMCU` 官方固件，可直接开机使用。如需升级或切换固件，请参考仓库中的 [固件烧录说明](../../firmware/README.md)。

仓库提供的固件均为合并固件，使用烧录工具时需要写入 `Flash` 偏移地址 `0x0`。

当前推荐固件为 `rymcu-V2.3.28-merged.bin`，旧版 `rymcu-V2.3.19-merged.bin` 仍保留用于回退。V2.3.28 预编译固件包含天气、日历、Codex 状态应用、Smart Home MQTT/Endpoint、NES 启动器和 NES 专用启动模式；不包含 2026-07-28 提交 `b1d1c08` 中后续的 NES 显示、音频和音量控制调整。

## 2. 开机与主界面

### 2.1 开机

1. 长按电源键约 `3` 秒开机,开机状态下长按关机。
2. 如果电池电量不足，请使用 `USB Type-C` 数据线连接电脑或 `5V` 电源供电。
3. 屏幕点亮后进入 `Home` 主界面，界面会显示 `rymcu-bigsmart` 和当前固件版本。
4. 如需查看串口日志，请使用串口工具连接设备对应的 `COM` 口。

<p align="center">BigSmart Home 主界面</p>

### 2.2 主界面与应用

在 `Home` 主界面左右滑动可切换应用页面。常见应用如下：

| 应用 | 用途 |
|---|---|
| Xiaozhi | 进入小智语音助手 |
| Settings | 配置 Wi-Fi、服务器、显示等设置 |
| Music | 播放 SD 卡中的 MP3 |
| Radio | 播放网络电台 |
| Weather | 查看天气信息 |
| Calendar | 查看日历 |
| Video | 播放 `/sdcard/videos` 中的视频资源 |
| Image | 查看图片资源 |
| Camera | 使用 GC0308 摄像头 |
| Gyro | 查看 QMI8658 姿态和传感器信息 |
| Codex | 查看 Codex 状态和桥接设置入口 |
| NES | 从 SD 卡选择 NES ROM，并重启进入 NES 专用启动模式 |
| Games | 进入游戏相关功能 |
| USB Disk | 重启进入 USB 磁盘模式，将 SD 卡共享给电脑 |

触摸屏可用于点击应用图标、返回上级页面、选择文件和调整设置。

<p align="center">BigSmart 应用页面</p>

## 3. Wi-Fi 配网

首次使用时需要先配置 `Wi-Fi`。`BigSmart` 支持三种配网方式：屏幕配网、热点网页配网和微信小程序蓝牙配网，任选一种完成即可。

打开 `Settings` 应用，进入 `Wi-Fi` 设置页。

<p align="center">Wi-Fi 设置入口</p>

**注意：BigSmart 仅支持 2.4 GHz Wi-Fi。**

### 3.1 屏幕配网

点击 `Screen WiFi` 进入屏幕配网页面，输入 `Wi-Fi` 名称和密码后，点击 `Connect` 连接网络。

<p align="center">屏幕配网页面</p>

### 3.2 热点网页配网

点击 `Web Setup` 进入热点配网页面。使用手机连接屏幕上显示的热点，例如 `Xiaozhi-11F0`，手机通常会自动跳转到配网页面；若未自动跳转，可手动打开浏览器访问提示页面并填写 `Wi-Fi` 信息。

<p align="center">热点网页配网</p>

### 3.3 微信小程序蓝牙配网

点击 `BLE Setup` 进入蓝牙配网页面。使用微信扫描屏幕二维码，或在微信中搜索小程序“艾塔达克”。首次使用时请先注册或登录账号。

<p align="center">微信小程序蓝牙配网入口</p>

小程序操作流程如下：

| 打开小程序 | 选择蓝牙配网 | 完成网络配置 |
|---|---|---|
| 微信小程序步骤 1 | 微信小程序步骤 2 | 微信小程序步骤 3 |

## 4. 服务商与设备绑定

### 4.1 服务商设置

使用`xiaozhi`语音助手前还需设置服务器地址，通过屏幕配置支持3种服务商配置，打开 `Settings` 应用，点击`Advanced`选项，如下图所示。

<p align="center">高级服务设置</p>

其中，`atdak`为`RYMCU`官方服务器，`tenclass`为虾哥小智AI官方服务器，`custom`为自定义服务器，可输入自己的服务器地址。

**设备出场默认使用RYMCU官方服务器。**

### 4.2 设备绑定

首次使用，进入 `Xiaozhi app` 后，设备屏幕会显示激活码或绑定码；在对应小程序或网页后台输入该验证码并确认绑定。

<p align="center">设备绑定码</p>

**以下3种选择1种即可（务必要与设置的服务商一致），出厂默认选择第1种。**

#### 4.2.1 RYMCU官方服务器验证码绑定方法

请登录微信小程序“艾塔达克”，进行绑定如下图所示。

| 设备列表入口 | 输入绑定信息 |
|---|---|
| 设备绑定步骤 1 | 设备绑定步骤 2 |

#### 4.2.2 虾哥小智AI官方服务器验证码绑定方法

登录官方后台https://xiaozhi.me/console/agents， 先点击“设备管理”，再点击“添加设备”，可在添加设备弹窗中输入设备播报或屏幕显示的 6 位验证码。

<p align="center">网页后台添加设备</p>

#### 4.2.3 自定义服务器验证码绑定方法

按照自定义服务器进行绑定。

另外，`RYMCU`官方有开源服务器，可以进行自行部署，但需要一定的基础，服务器链接：https://github.com/ruanrongman/IntelliConnect

## 5. AI 助手使用

**`wifi`和服务器配置好之后，点击屏幕`xiaozhi app`，进入AI助手，初始化完成进入`idle`页面后，通过语音”你好，小智“唤醒，也可以按中间的`boot`按键唤醒。**

| 待机页面 | 唤醒页面 |
|---|---|
| AI 助手待机页面 | AI 助手唤醒页面 |

## 6. 音乐与视频播放

点击屏幕的`Music app`和`Video app`即可播放`SD`卡`mp3`音乐和视频。

| 音乐播放 | 视频播放 |
|---|---|
| 音乐播放界面 | 视频播放界面 |

**需提前将`mp3`格式音乐和视频文件放入`SD`卡的`music`和`videos`文件夹，操作方法详见下一节。**

## 7. USB 磁盘模式

`USB` 磁盘模式会把 `SD` 卡作为 `U`盘共享给电脑，适合快速复制音乐、视频、背景图和其他资源。

进入方式：

点击屏幕`USB Disk app`进入`USB`转U盘模式，使用`USB`线连接计算机，计算机即可看到该`U`盘。

<p align="center">USB 磁盘中的 SD 卡目录</p>

**将`MP3`拷贝到`music`文件夹即可。**

**常规视频文件需要转换成适合`bigsmart AI`助手播放的模式，放到`videos`目录下即可，使用仓库中的 [视频转换器](video-converter.md) 进行转换。**

## 8. 网络电台

点击`radio app`可以播放网络电台。

<p align="center">网络电台</p>

## 9. 游戏

点击`Games app`有多个游戏可玩。

| 游戏列表 | 迷宫游戏 |
|---|---|
| 游戏列表 | 迷宫游戏 |

## 10. 扩展能力

`BigSmart` 固件还注册了多种 `MCP` 工具和本地功能：

| 能力 | 说明 |
|---|---|
| 天气与日历 | V2.3.28 固件提供天气和日历应用入口 |
| Codex 状态 | 可在设备端查看 Codex 运行状态和桥接设置入口 |
| RGB LED | 支持设置 RGB 颜色和关闭灯光 |
| IMU 姿态与晃动 | QMI8658 可读取姿态数据并支持晃动检测 |
| Smart Home MQTT/Endpoint | 支持配置 Smart Home MQTT broker，并通过 MCP Endpoint 桥接到同一套智能家居工具 |
| NES 专用启动模式 | 从 NES 启动器选择 SD 卡中的 ROM 后重启进入专用模式 |
| 摄像头 | GC0308 采用懒加载方式，首次进入 Camera 或请求摄像头能力时初始化 |

## 11. 常见问题

| 问题 | 排查建议 |
|---|---|
| 开机屏幕不亮 | 确认长按电源键约 3 秒，检查电池电量、USB 供电和数据线 |
| 电脑没有串口 | 更换可传输数据的 USB 线，检查驱动和设备管理器 |
| Wi-Fi 扫描不到 | 确认使用 2.4 GHz Wi-Fi，靠近路由器后重试 |
| 无法进入配网 | 从 `Settings` 进入 Wi-Fi 页面，或重启后重新进入配网流程 |
| SD 卡挂载失败 | 确认 FAT32 格式，重新插拔或更换 SD 卡 |
| Video 没有文件 | 确认文件放在 `/sdcard/videos`，且至少有 `.mjpg` 文件 |
| 视频有画面无声音 | 确认存在同名 `.mp3` 文件 |
| 视频速度不对 | 确认同名 `.fps` 文件内容是整数帧率 |
| MP3 播放失败 | 确认路径为 `/sdcard/...` 的绝对路径，文件后缀为 `.mp3` |
| USB 磁盘模式进不去 | 启动或复位前按住 GPIO10，并确认插入 SD 卡 |
| NES 看不到游戏 | 确认 SD 卡已挂载，并将 `.nes` ROM 放入固件识别的 SD 卡目录 |
| Codex 状态无法连接 | 确认设备和 PC 在同一局域网，并在 Codex 应用中配置正确的桥接地址 |
| 语音识别回声明显 | 空闲状态双击 Boot 切换设备侧 AEC |

## 12. 后续阅读

- [产品介绍书](product-brief.md)
- [用户详细使用手册](user-manual.md)
- [硬件配置说明](hardware.md)
- [视频转换器使用说明](video-converter.md)

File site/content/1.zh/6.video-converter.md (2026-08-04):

---
title: 视频转换器使用说明
description: 将常见视频转换为 BigSmart 固件可播放资源的工具说明。
navigation:
  title: 视频转换器使用说明
  icon: i-lucide-video
links:
  - label: English
    icon: i-lucide-languages
    to: /en/docs/video-converter
---
RYMCU BigSmart 视频转换器用于把常见视频文件转换为 BigSmart 固件可播放的资源文件。转换完成后会生成同名的 `.mjpg`、`.mp3` 和 `.fps` 文件，将它们复制到 SD 卡的 `/videos` 目录即可在设备端播放。

## 工具位置

```text
tools/video-converter/RYMCU-Video-Converter.exe
```

工具已内置 FFmpeg，目标电脑不需要额外安装 FFmpeg。

## 支持格式

支持常见视频格式，包括：

- `mp4`
- `mov`
- `avi`
- `mkv`
- `flv`
- `webm`
- `m4v`
- `wmv`
- `3gp`

## 转换步骤

1. 双击 `tools/video-converter/RYMCU-Video-Converter.exe`。
2. 点击“选择视频”，或把视频文件拖到窗口中。
3. 保持默认参数，或按需要调整转换参数。
4. 点击“开始转换”。
5. 转换完成后，在输出目录中确认生成了三个文件：

```text
视频名.mjpg
视频名.mp3
视频名.fps
```

## 推荐参数

| 参数 | 推荐值 | 说明 |
|---|---|---|
| 视频帧率 | 8-12 fps | 通常推荐范围，兼顾流畅度和设备解码压力 |
| 动作较快视频 | 12-15 fps | 可提升流畅度，但文件会变大，设备解码压力也更高 |
| JPEG 质量 | 8 | 默认推荐值 |
| MP3 采样率 | 44100 Hz | 默认推荐值 |
| 低容量音频 | 16000 Hz | 只想减小音频文件时可选 |

配套固件会读取同名 `.fps` 文件保持音画同步。

## 复制到 SD 卡

将转换得到的三个文件复制到 SD 卡的 `/videos` 目录：

```text
/sdcard/videos/视频名.mjpg
/sdcard/videos/视频名.mp3
/sdcard/videos/视频名.fps
```

如果 SD 卡中没有 `videos` 目录，请先手动创建。

## 注意事项

- 三个输出文件必须保持相同文件名，只允许扩展名不同。
- 建议视频文件名使用英文、数字、短横线或下划线，减少不同系统下的路径兼容问题。
- 帧率越高、画面质量越高，生成文件越大，设备播放时的解码压力也越高。
- 如播放卡顿，可优先降低帧率或 JPEG 质量。

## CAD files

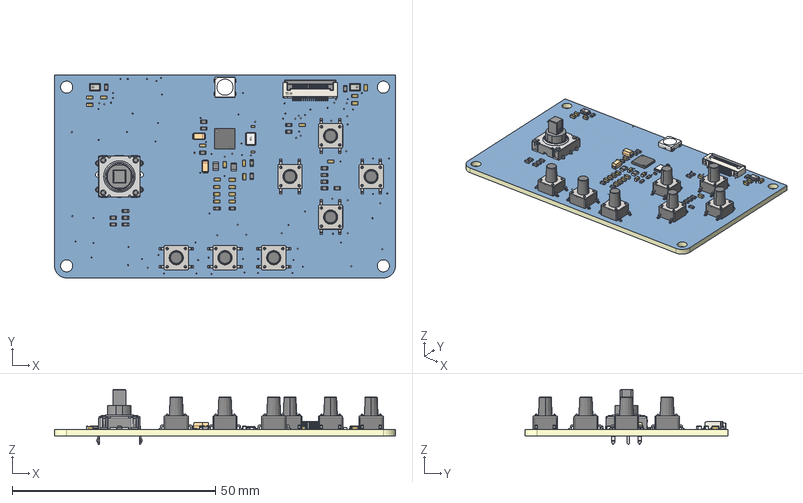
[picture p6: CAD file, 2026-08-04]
enclosure/3D_bs-mic_2026-02-01.step
84.0 x 50.0 x 13.6 mm
Board~GPN9
TopCopper~GPN9
BottomCopper~GPN9
TopFpcStiffener~GPN9
BottomFpcStiffener~GPN9
L0805~R0805_L2.0-W1.3-H0.6~MuWV x 2
C0402_1~C0402_L1.0-W0.5-H0.5~T4Gv x 2
MIC-SMD_4P-L2.8-W1.9-P1.84-TL_ZTS6117~MIC-SMD_4P-L2.8-W1.9-P1.84-TL_ZTS6117~w4WU x 2
LED-SMD_4P-L5.0-W5.0-BL_XL-5050RGBC~LED-SMD_4P-L5.0-W5.0-BL_XL-5050RGBC~jsYA
CRYSTAL-SMD_4P-L3.2-W2.5-BL~CRYSTAL-SMD_4P-L3.2-W2.5-BL~fnKJ
CAP-SMD_L3.2-W1.6-RD-C7171~CASE-A_L3.2-W1.6-H1.6~tkNP x 2
R0603_1~R0603~hsxk x 21
SW-SMD_4P-L6.0-W6.0-P4.50-LS9.0-1~SW-SMD_4P-L6.0-W6.0-P4.50-LS9.0-1~rKeq x 7
C0603~C0603_L1.6-W0.8-H0.8~rf5B x 20
FPC-SMD_18P-P0.50_FPC-05F-18PH20~FPC-SMD_18P-P0.50_FPC-05F-18PH20~gSdN
SW-TH_WS-1004-ARL10026~SW-TH_WS-1004-ARL10026~6qvt
QFN-32_L5.0-W5.0-P0.50-BL-EP3.7~QFN-32_L5.0-W5.0-H0.8-P0.50-BL-EP3.7~NWWf

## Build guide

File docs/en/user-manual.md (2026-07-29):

# RYMCU BigSmart User Manual

[中文](../zh/user-manual.md)

## 1. Before You Start

### 1.1 Required Items

| Item | Purpose |
|---|---|
| RYMCU BigSmart development board | Main device |
| USB Type-C data cable | Power, serial logs, firmware flashing |
| 5 V USB power supply or computer USB port | Power |
| MicroSD card | Stores MP3, video, and other resources |
| Bluetooth HID gamepad | Optional game controller |
| 2.4G Wi-Fi network | Xiaozhi, internet radio, MQTT, and other connected features |

### 1.2 Notes

- Use a USB cable that supports data transfer. Charge-only cables cannot flash firmware or show serial logs.
- Format the MicroSD card as FAT32.
- ESP32-S3 supports 2.4G Wi-Fi only. Do not use a 5G-only network.
- Camera, audio, display, and Wi-Fi features all consume memory. During development, verify basic features first, then enable advanced features one by one.
- This manual uses the BigSmart Xiaozhi firmware under `E:\RYMCU\xiaozhi` as the software reference. If you use other firmware, button behavior and menu flow may differ.

## 2. Development Environment

### 2.1 Recommended Environment

| Tool | Recommended version / note |
|---|---|
| ESP-IDF | 5.4 or later |
| IDE | VSCode, Cursor, or command line |
| Serial terminal | ESP-IDF Monitor, PuTTY, MobaXterm, or another serial terminal |
| Firmware project | / |
| Hardware repository | / |

## 3. Firmware Flashing

### 3.1 Flash the Repository Merged Firmware Image

This repository provides BigSmart merged firmware images:

```text
firmware/rymcu-V2.3.28-merged.bin
firmware/rymcu-V2.3.19-merged.bin
firmware/xiaozhi-esp32-merged.bin
firmware/espressif-brookesia-merged.bin
```

The RYMCU official firmware `rymcu-V2.3.28-merged.bin` is recommended as the default. `rymcu-V2.3.19-merged.bin` remains available as a legacy fallback.

The V2.3.28 prebuilt image includes Weather, Calendar, Codex Status, Smart Home MQTT/Endpoint, the NES launcher, and NES dedicated boot mode. It does not include the later NES display, audio, and volume-control changes from the 2026-07-28 commit `b1d1c08`.

You can flash it with ESP-IDF, `esptool.py`, or a GUI flashing tool. A common command-line method is:

```powershell
esptool.py --chip esp32s3 -p COM_PORT -b 460800 write_flash 0x0 firmware\rymcu-V2.3.28-merged.bin
```

### 3.2 Enter Download Mode

If automatic flashing fails, enter download mode manually:

1. Hold the Boot button.
2. Reset or power-cycle the board.
3. Release the Boot button.
4. Run the flashing command again.

## 4. First Boot and Wi-Fi Provisioning

### 4.1 Startup Check

After flashing, the device restarts. In a normal startup:

- The screen turns on and shows the Xiaozhi UI.
- Serial logs print board initialization information.
- If an SD card is present, logs show it mounted at `/sdcard`.
- If Wi-Fi is not configured, the device enters provisioning.

### 4.2 Wi-Fi Provisioning

The Xiaozhi reference project includes BluFi provisioning documentation. A typical flow:

1. Enable `WiFi Configuration Method -> Esp Blufi` during build configuration.
2. On first boot without saved Wi-Fi credentials, the device enters provisioning automatically.
3. Use the EspBlufi app or another compatible BluFi client to find the device.
4. Connect to the device and enter the 2.4G Wi-Fi SSID and password.
5. After connection succeeds, the device saves the configuration and connects automatically on later boots.

To reprovision Wi-Fi after the firmware is running, use one of these methods:

- Click the Boot button during startup to enter provisioning.
- Request reprovisioning through the MCP tool `self.system.reconfigure_wifi`.
- Clear NVS or erase data during flashing, then reboot.

## 5. Buttons and Basic Interaction

| Operation | Function |
|---|---|
| Hold power button for about 3 seconds | Power on/off, depending on the power management circuit state |
| Click Boot | Enter provisioning during startup; toggle conversation state during runtime |
| Double-click Boot | Toggle device-side AEC while idle, when `CONFIG_USE_DEVICE_AEC` is enabled |
| Press GPIO10/PTT | Start voice listening |
| Release GPIO10/PTT | End voice listening |
| Tap or swipe touch screen | Depends on the current firmware UI and application logic |

## 6. Voice Assistant

### 6.1 Conversation

1. Make sure the device is connected to Wi-Fi.
2. Click Boot to switch to conversation/listening state, or hold GPIO10/PTT to start speaking.
3. Speak your question or command.
4. Release PTT or wait for the device to stop listening.
5. The device plays the response through the speaker and updates the screen state.

### 6.2 AEC Switching

Device-side AEC suppresses speaker echo. When enabled in firmware, double-click Boot while idle to toggle AEC. If the device frequently captures its own speaker output during recognition, try enabling AEC. In simpler acoustic environments, you may disable it to reduce processing load.

## 7. SD Card Usage

### 7.1 Format and Directories

Format the MicroSD card as FAT32 and create directories as needed:

```text
/sdcard
├── music
│   ├── song1.mp3
│   └── song2.mp3
├── test.mp3
└── videos
    ├── demo.mjpg
    ├── demo.mp3
    └── demo.fps
```

### 7.2 Check SD Card Mounting

If the startup log contains `SD card mounted at /sdcard`, the card mounted successfully. You can also call `self.media.list_mp3_files` to check whether MP3 files can be read.

## 8. Local MP3 Playback

### 8.1 Supported Tools

| Function | MCP tool |
|---|---|
| Play a specific MP3 | `self.media.play_mp3` |
| Stop playback | `self.media.stop_mp3` |
| List MP3 files | `self.media.list_mp3_files` |
| Play a test file | `self.media.play_test_mp3` |
| Get playback state | `self.media.get_mp3_state` |
| Next track | `self.media.play_next` |
| Previous track | `self.media.play_previous` |

### 8.2 Examples

Play music from the SD card:

```json
{
  "tool": "self.media.play_mp3",
  "arguments": {
    "filepath": "/sdcard/music/song1.mp3"
  }
}
```

List MP3 files under `/sdcard`:

```json
{
  "tool": "self.media.list_mp3_files",
  "arguments": {
    "directory": "/sdcard"
  }
}
```

## 9. Internet Radio

After the device is online, internet radio tools can play network audio streams.

| Function | MCP tool |
|---|---|
| Play station | `self.radio.play_url` |
| Stop radio | `self.radio.stop` |
| Get status | `self.radio.get_status` |

Example:

```json
{
  "tool": "self.radio.play_url",
  "arguments": {
    "station_name": "Hit FM"
  }
}
```

## 10. Weather, Calendar, Codex, and NES

The V2.3.28 firmware adds or improves several Launcher app entries:

| App | Description |
|-----|---|
| Weather | Shows connected weather information |
| Calendar | Shows calendar information |
| Codex | Shows Codex runtime status and bridge settings |
| NES | Selects a `.nes` ROM from the SD card and reboots into NES dedicated boot mode |

The Codex app only provides the device-side status and bridge settings entry; PC-side bridge scripts are not published in the BigSmart-Open repository. NES behavior is limited to the V2.3.28 prebuilt image and does not include the later NES display, audio, and volume-control changes from the 2026-07-28 commit `b1d1c08`.

## 11. RGB LED and Smart Home MQTT/Endpoint

### 11.1 Direct RGB Control

Set the RGB LED:

```json
{
  "tool": "self.light.set_rgb_color",
  "arguments": {
    "red": 255,
    "green": 100,
    "blue": 50
  }
}
```

Turn off the RGB LED:

```json
{
  "tool": "self.light.turn_off",
  "arguments": {}
}
```

### 11.2 Smart Home MQTT Overview

The V2.3.28 firmware uses the RYMCU Smart Home MQTT protocol to control third-party smart home devices. The MQTT topic root is `rymcu/home/v1`; devices interact with BigSmart through pair codes, discovery announcements, state reports, and command topics.

There are two upper-level control paths:

- Local Xiaozhi session MCP: the voice service calls `self.smart_home.*` tools on the device.
- External MCP Endpoint Bridge: an endpoint written during provisioning calls the same `self.smart_home.*` tools, and Smart Home MQTT still sends the final commands.

Common tools:

| Function | MCP tool |
|---|---|
| Set MQTT broker | `self.smart_home.set_mqtt_endpoint` |
| Connect Smart Home MQTT | `self.smart_home.connect` |
| Disconnect | `self.smart_home.disconnect` |
| Get status | `self.smart_home.get_status` |
| Scan devices | `self.smart_home.scan_devices` |
| List devices | `self.smart_home.list_devices` |
| Control device | `self.smart_home.control_device` |

Set the broker:

```json
{
  "tool": "self.smart_home.set_mqtt_endpoint",
  "arguments": {
    "endpoint": "broker-cn.emqx.io:1883",
    "confirm": true
  }
}
```

Connect and scan devices:

```json
{
  "tool": "self.smart_home.connect",
  "arguments": {}
}
```

```json
{
  "tool": "self.smart_home.scan_devices",
  "arguments": {}
}
```

Control a discovered device:

```json
{
  "tool": "self.smart_home.control_device",
  "arguments": {
    "device_id": "lamp-bedroom-01",
    "action": "turn_on",
    "entity_id": "main",
    "params": "{}"
  }
}
```

Provisioning custom data also supports two prefixes:

- `mqtt:<host[:port]>`: save the Smart Home MQTT broker.
- `mcp:<endpoint>`: save the external MCP Endpoint address.

## 12. IMU Attitude and Shake Detection

BigSmart includes a QMI8658 six-axis sensor. After firmware startup, sensor data is read periodically and shake detection is started. You can read attitude angles, acceleration, and gyroscope data through MCP tools:

```json
{
  "tool": "self.imu.get_attitude_angles",
  "arguments": {}
}
```

Typical uses:

- Shake to wake or switch UI.
- Motion-controlled mini games.
- Device attitude display.
- Interactive installation triggers.

## 13. Camera Usage

BigSmart uses a GC0308 camera with 640 x 480 @ 16 FPS hardware support. The reference firmware uses lazy initialization: the camera is not initialized during startup and is only initialized on the first camera request, reducing startup memory pressure.

Suggestions:

- Make sure GC0308-related firmware configuration is enabled.
- Call the camera only when image capability is needed to avoid competing with audio, Wi-Fi, and large UI tasks for memory.
- If the image orientation is wrong, check mirror and flip settings in firmware.

## 14. Troubleshooting

| Problem | Possible cause | Solution |
|---|---|---|
| Computer cannot detect serial port | Charge-only USB cable, missing driver, device not powered | Replace cable, install driver, check power |
| Flashing fails | Not in download mode or serial port is occupied | Enter download mode with Boot + reset, close serial terminal, retry |
| Cannot connect Wi-Fi | 5G network, wrong password, weak signal | Use 2.4G Wi-Fi, reprovision, move closer to router |
| No sound | Volume too low, amplifier not enabled, audio init failed | Check serial logs and ES8311/ES7210 initialization |
| Poor voice recognition | Noisy environment, too far from mic, unsuitable AEC state | Speak closer to the device, double-click Boot to toggle AEC |
| SD card cannot mount | Not FAT32, poor contact, damaged card | Reformat, reinsert, replace card |
| MP3 not found | Wrong path or unsupported format | Use absolute path and confirm `.mp3` extension |
| Smart Home MQTT connection fails | Wrong broker address, wrong port, network unreachable, or Smart Home MQTT disabled | Query `self.smart_home.get_status` and reconfigure the broker in Settings > Advanced or through the MCP tool |
| NES games are not listed | SD card is not mounted, directory does not match firmware scanning rules, or ROM extension is wrong | Confirm the SD card is FAT32-readable and add `.nes` ROMs |
| Codex status cannot connect | PC-side bridge is not running, bridge address is wrong, or the PC is not on the same LAN | Check device-to-PC network access and configure the bridge address in the Codex app |

## 15. Hardware Maintenance

- Power off before plugging or unplugging the display, camera, microphone board, or other flex cables.
- Pay attention to battery polarity and charging safety when using battery power.
- Enclosure files are in `enclosure/`. When modifying the structure, consider screen, button, microphone openings, and speaker acoustic cavity.
- Before adding new peripherals, check [Hardware Configuration](hardware.md) to avoid GPIO conflicts.

## 16. References

- Project hardware documentation: [hardware.md](hardware.md)

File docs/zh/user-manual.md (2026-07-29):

# RYMCU BigSmart 用户详细使用手册

[English](../en/user-manual.md)

## 1. 使用前准备

### 1.1 物品清单

| 项目 | 用途 |
|---|---|
| RYMCU BigSmart AI助手 | 主设备 |
| USB Type-C 数据线 | 供电、串口日志、固件烧录 |
| 5V USB 电源或电脑 USB 口 | 供电 |
| MicroSD 卡 | 存放 MP3、视频和其他资源 |
| 蓝牙 HID 手柄 | 游戏控制，可选 |
| 2.4G Wi-Fi 网络 | 小智联网、网络电台、MQTT 等功能 |

### 1.2 注意事项

- 使用可传输数据的 USB 线，只有充电功能的线无法烧录或查看串口。
- MicroSD 卡建议格式化为 FAT32。
- ESP32-S3 只支持 2.4G Wi-Fi，请不要选择 5G-only 网络。
- 摄像头、音频、屏幕和 Wi-Fi 都会占用较多内存，开发调试时建议先验证基础功能，再逐项打开高级功能。
- 本手册的软件操作以 `E:\RYMCU\xiaozhi` 中的 BigSmart 小智固件为参考；如果你使用其他固件，按键和菜单行为可能不同。

## 2. 开发环境

### 2.1 推荐环境

| 工具 | 建议版本/说明 |
|---|---|
| ESP-IDF | 5.4 及以上 |
| IDE | VSCode、Cursor 或命令行 |
| 串口工具 | ESP-IDF Monitor、PuTTY、MobaXterm 或其他串口终端 |
| 固件工程 | 当前仓库 |
| 硬件资料 | 当前仓库 |

## 3. 固件烧录

### 3.1 使用仓库内合并固件烧录

当前仓库已提供 BigSmart 合并固件：

```text
firmware/rymcu-V2.3.28-merged.bin
firmware/rymcu-V2.3.19-merged.bin
firmware/xiaozhi-esp32-merged.bin
firmware/espressif-brookesia-merged.bin
```

默认建议先烧录 RYMCU 官方固件 `rymcu-V2.3.28-merged.bin`。旧版 `rymcu-V2.3.19-merged.bin` 仍保留用于回退。

V2.3.28 预编译固件包含天气、日历、Codex 状态应用、Smart Home MQTT/Endpoint、NES 启动器和 NES 专用启动模式。该文件不包含 2026-07-28 提交 `b1d1c08` 中后续的 NES 显示、音频和音量控制调整。

可使用 ESP-IDF、esptool 或图形化烧录工具写入 ESP32-S3。若使用命令行，常见方式为：

```powershell
esptool.py --chip esp32s3 -p COM端口 -b 460800 write_flash 0x0 firmware\rymcu-V2.3.28-merged.bin
```

### 3.2 进入下载模式

如果自动下载失败，可按以下方式手动进入下载模式：

1. 按住 Boot 键。
2. 复位或重新上电。
3. 松开 Boot 键。
4. 重新执行烧录命令。

## 4. 首次启动与配网

### 4.1 启动检查

烧录完成后设备会重启。正常情况下可以看到：

- 屏幕亮起并显示小智相关界面。
- 串口日志打印板级初始化信息。
- SD 卡存在时，日志显示挂载到 `/sdcard`。
- Wi-Fi 未配置时，设备进入配网流程。

### 4.2 Wi-Fi 配网

小智参考工程包含 BluFi 配网文档。典型流程：

1. 编译时启用 `WiFi Configuration Method -> Esp Blufi`。
2. 设备首次启动且没有保存的 Wi-Fi 时自动进入配网。
3. 手机使用 EspBlufi App 或兼容 BluFi 客户端搜索设备。
4. 连接设备后输入 2.4G Wi-Fi 的 SSID 和密码。
5. 设备连接成功后会保存配置，后续自动联网。

如果固件进入运行态后需要重新配网，可使用以下方式之一：

- 设备启动阶段单击 Boot 键进入配网。
- 通过 MCP 工具 `self.system.reconfigure_wifi` 请求重新配网。
- 清除 NVS 或重新烧录擦除数据后重新启动。

## 5. 按键与基础交互

| 操作 | 功能 |
|---|---|
| 电源键长按约 3 秒 | 开机/关机，取决于电源管理电路状态 |
| Boot 键单击 | 启动阶段进入配网；运行时切换对话状态 |
| Boot 键双击 | 在空闲状态切换设备侧 AEC 开关，需固件启用 `CONFIG_USE_DEVICE_AEC` |
| GPIO10/PTT 键按下 | 开始监听语音 |
| GPIO10/PTT 键松开 | 结束监听语音 |
| 触摸屏点击/滑动 | 取决于当前固件界面和应用逻辑 |

## 6. 语音助手使用

### 6.1 对话

1. 确保设备已连接 Wi-Fi。
2. 单击 Boot 键切换到对话/监听状态，或按住 GPIO10 PTT 键开始说话。
3. 对设备说出问题或指令。
4. 松开 PTT 键或等待设备结束监听。
5. 设备通过扬声器播报回复，屏幕同步显示状态。

### 6.2 AEC 切换

设备侧 AEC 用于抑制扬声器回声。固件启用后，在空闲状态双击 Boot 键可切换 AEC。若语音识别时设备自己的播报声容易被再次采集，可尝试开启 AEC；若环境较简单，也可以关闭以降低处理开销。

## 7. SD 卡使用

### 7.1 格式与目录

推荐将 MicroSD 卡格式化为 FAT32，并按需创建目录：

```text
/sdcard
├── music
│   ├── song1.mp3
│   └── song2.mp3
└── test.mp3
```

### 7.2 SD 卡挂载检查

启动日志中若出现 `SD card mounted at /sdcard`，说明挂载成功。也可以调用 `self.media.list_mp3_files` 检查是否能读取 MP3 文件。

## 8. 本地 MP3 播放

### 8.1 支持能力

| 功能 | MCP 工具 |
|---|---|
| 播放指定 MP3 | `self.media.play_mp3` |
| 停止播放 | `self.media.stop_mp3` |
| 列出 MP3 文件 | `self.media.list_mp3_files` |
| 播放测试文件 | `self.media.play_test_mp3` |
| 查询播放状态 | `self.media.get_mp3_state` |
| 下一首 | `self.media.play_next` |
| 上一首 | `self.media.play_previous` |

### 8.2 示例

播放 SD 卡中的音乐：

```json
{
  "tool": "self.media.play_mp3",
  "arguments": {
    "filepath": "/sdcard/music/song1.mp3"
  }
}
```

列出 `/sdcard` 下的 MP3 文件：

```json
{
  "tool": "self.media.list_mp3_files",
  "arguments": {
    "directory": "/sdcard"
  }
}
```

## 9. 网络电台

联网后可使用网络电台功能。常用工具：

| 功能 | MCP 工具 |
|---|---|
| 播放电台 | `self.radio.play_url` |
| 停止电台 | `self.radio.stop` |
| 查询状态 | `self.radio.get_status` |

示例：

```json
{
  "tool": "self.radio.play_url",
  "arguments": {
    "station_name": "动感101"
  }
}
```

## 10. 天气、日历、Codex 与 NES

V2.3.28 固件在 Launcher 中新增或完善了多个应用入口：

| 应用 | 说明 |
|---|---|
| Weather | 查看联网天气信息 |
| Calendar | 查看日历信息 |
| Codex | 查看 Codex 运行状态和桥接设置入口 |
| NES | 从 SD 卡选择 `.nes` ROM，并重启进入 NES 专用启动模式 |

Codex 应用只提供设备端状态和桥接设置入口；PC 端桥接脚本不随 BigSmart-Open 仓库发布。NES 相关体验以 V2.3.28 预编译固件为准，不包含 2026-07-28 提交 `b1d1c08` 中后续的 NES 显示、音频和音量控制调整。

## 11. RGB 灯与 Smart Home MQTT/Endpoint

### 11.1 直接控制 RGB

设置 RGB LED：

```json
{
  "tool": "self.light.set_rgb_color",
  "arguments": {
    "red": 255,
    "green": 100,
    "blue": 50
  }
}
```

关闭 RGB LED：

```json
{
  "tool": "self.light.turn_off",
  "arguments": {}
}
```

### 11.2 Smart Home MQTT 概览

V2.3.28 固件使用 RYMCU Smart Home MQTT 协议控制第三方智能家居设备。底层 MQTT topic 根前缀为 `rymcu/home/v1`，设备需要通过配对码、发现广播、状态上报和命令 topic 与 BigSmart 交互。

上层控制入口有两种：

- 本地小智会话 MCP：语音服务直接调用设备上的 `self.smart_home.*` 工具。
- 外部 MCP Endpoint Bridge：通过配网写入的 Endpoint 调用同一批 `self.smart_home.*` 工具，最终仍由 Smart Home MQTT 下发。

常用工具：

| 功能 | MCP 工具 |
|---|---|
| 设置 MQTT broker | `self.smart_home.set_mqtt_endpoint` |
| 连接 Smart Home MQTT | `self.smart_home.connect` |
| 断开连接 | `self.smart_home.disconnect` |
| 查询状态 | `self.smart_home.get_status` |
| 扫描设备 | `self.smart_home.scan_devices` |
| 列出设备 | `self.smart_home.list_devices` |
| 控制设备 | `self.smart_home.control_device` |

设置 broker：

```json
{
  "tool": "self.smart_home.set_mqtt_endpoint",
  "arguments": {
    "endpoint": "broker-cn.emqx.io:1883",
    "confirm": true
  }
}
```

连接并扫描设备：

```json
{
  "tool": "self.smart_home.connect",
  "arguments": {}
}
```

```json
{
  "tool": "self.smart_home.scan_devices",
  "arguments": {}
}
```

控制已发现设备：

```json
{
  "tool": "self.smart_home.control_device",
  "arguments": {
    "device_id": "lamp-bedroom-01",
    "action": "turn_on",
    "entity_id": "main",
    "params": "{}"
  }
}
```

配网自定义数据也支持两个前缀：

- `mqtt:<host[:port]>`：保存 Smart Home MQTT broker。
- `mcp:<endpoint>`：保存外部 MCP Endpoint 地址。

## 12. IMU 姿态与晃动检测

BigSmart 板载 QMI8658 六轴传感器。固件启动后会周期读取传感器数据，并启动晃动检测。可通过 MCP 工具读取姿态角、加速度和陀螺仪数据：

```json
{
  "tool": "self.imu.get_attitude_angles",
  "arguments": {}
}
```

可用于以下场景：

- 晃动唤醒或切换界面。
- 体感控制小游戏。
- 设备姿态显示。
- 交互装置触发条件。

## 13. 摄像头使用

BigSmart 使用 GC0308 摄像头，硬件支持 640 x 480 @ 16 FPS。参考固件采用懒加载方式：启动阶段不立即初始化摄像头，首次请求摄像头能力时才初始化，以降低启动阶段内存压力。

使用建议：

- 确保固件启用 GC0308 相关配置。
- 需要图像能力时再调用摄像头，避免与音频、Wi-Fi、大型 UI 同时抢占内存。
- 若画面方向异常，可检查固件中的镜像和翻转设置。

## 14. 常见问题

| 问题 | 可能原因 | 处理方法 |
|---|---|---|
| 电脑识别不到串口 | USB 线仅供电、驱动缺失、设备未上电 | 更换数据线，安装驱动，检查电源 |
| 烧录失败 | 未进入下载模式或串口被占用 | 按 Boot + 复位进入下载模式，关闭串口终端后重试 |
| 连不上 Wi-Fi | 使用 5G 网络、密码错误、信号弱 | 使用 2.4G Wi-Fi，重新配网，靠近路由器 |
| 无声音 | 音量过低、功放未使能、音频初始化失败 | 查看串口日志，确认 ES8311/ES7210 初始化正常 |
| 语音识别差 | 环境噪声大、离麦克风太远、AEC 状态不合适 | 靠近设备说话，尝试双击 Boot 切换 AEC |
| SD 卡无法挂载 | 未格式化 FAT32、接触不良、卡损坏 | 重新格式化，重新插拔，更换 SD 卡 |
| 找不到 MP3 | 路径错误或文件格式不支持 | 使用绝对路径，确认文件后缀为 `.mp3` |
| Smart Home MQTT 连接失败 | broker 地址错误、端口错误、网络不可达或未启用 | 查询 `self.smart_home.get_status`，在 Settings > Advanced 或 MCP 工具中重新配置 broker |
| NES 看不到游戏 | SD 卡未挂载、目录不符合固件扫描规则或 ROM 后缀不正确 | 确认 SD 卡 FAT32 可读，并放入 `.nes` ROM |
| Codex 状态无法连接 | PC 端桥接服务未运行、桥接地址错误或不在同一局域网 | 确认设备和 PC 网络连通，并在 Codex 应用中配置正确桥接地址 |

## 15. 硬件维护

- 插拔屏幕、摄像头、麦克风板或其他排线前先断电。
- 使用电池供电时注意电池极性和充电安全。
- 外壳文件位于 `enclosure/`，修改结构时注意屏幕、按键、麦克风开孔和扬声器声腔。
- 二次开发新外设前，先查阅 [硬件配置说明](hardware.md) 避免 GPIO 冲突。

## 16. 参考资料

- 本项目硬件说明：[hardware.md](hardware.md)
